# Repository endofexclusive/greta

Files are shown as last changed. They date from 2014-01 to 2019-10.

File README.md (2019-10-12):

# About
Expansion board for the Amiga A500 computer providing SDRAM, Secure Digital
mass storage and Ethernet interface.

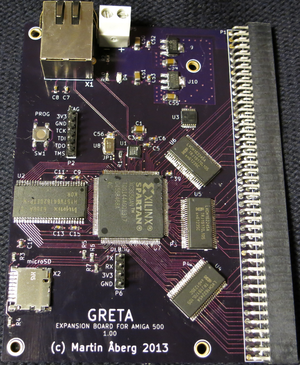
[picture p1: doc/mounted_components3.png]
board


# Features
- Attaches to the Amiga A500 expansion bus
- 8 MiB Fast RAM
  - Zero wait state
  - Always available to the system via Amiga AUTOCONFIG protocol
- SPI controller
  - For interfacing with Secure Digital storage
- 10/100Mbit Ethernet PHY

# Hardware overview
hw-overview
## FPGA
Xilinx Spartan-3AN is used for control logic. This FPGA device
is equipped with an internal bitstream flash.

## Bus transceivers
The Amiga computer uses 5V signalling while the FPGA and the other
expansion board components operate at 3.3V. Signal level conversion
and bus isolation is solved by using 5V-tolerant 3.3V drivers for
signals between the computer to the expansion board.

## Bus protocol
A500 expansion bus protocol is equivalent to the MC68000 processor
bus protocol. The MC68000 bus control signals are sampled by the
FPGA, synchronized, and bridged to an internal custom bus protocol
with time-slots allocated to on-board peripherals.

## Voltage regulators
3.3V and 1.2V are generated by on-board voltage regulators, powered
by the expansion bus connector.

## Clocking
A 50 MHz input clock is generated by the Ethernet PHY. This clock
is synchronous with the PHY RMII signals. The FPGA logic and SDRAM
operate at 133 MHz.

# Status
- Full support for the 8 MiB zero waitstate SDRAM is implemented.

- AmigaOS AUTOCONFIG for device discovery implemented.

- An SPI controller is implemented and is currently being used for
  developing an AmigaOS compliant disk controller driver with SCSI
  emulation.

- An Ethernet MAC with DMA is still to be implemented.

- Gerber files are readily available and can be sent to a PCB
  manufacturer for production. Refer to the schematic files for
  bill of materials (BOM).

# Documentation
Details of the design is documented in the
[Technical description](greta.pdf).

Schematic and layout files are available in the
[pcb](pcb) directory.
A PDF rendering of the schematic can be found in
[doc/schematic.pdf](doc/schematic.pdf).

# Tools
The following tools have been used in the development of hardware
and HDL:
- **KiCad**: schematic and PCB layout
- **GHDL**: RTL simulation and testbenches
- **Xilinx ISE**: Xilinx FPGA synthesis and layout

# Authors
Martin Åberg - <martin@fripost.org>

# License
All schematics, PCB layout and VHDL code described in this document
are released under the GNU General Public License.

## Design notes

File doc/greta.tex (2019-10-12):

\documentclass[a4paper]{report}
\usepackage[english]{babel}
\usepackage{siunitx}
\usepackage[utf8]{inputenc}
\usepackage{listings}
%See listings manual for parameters!!!
\usepackage{listings}
\lstset{
    language=VHDL,
%    basicstyle=\ttfamily
    basicstyle=\footnotesize \ttfamily
    % Fix for character in license unknown to "listings".
    \lstset{literate={Å}{{\AA}}1}
}

\usepackage{booktabs}
\usepackage{tikz-timing}[2009/12/09]
% Use tikz-timing library 'counters' to define a counter character.
% This character draws a 'D{<counter value>}' and increases the counter
% value by one. A reset character which resets the counter value 
% (by default to 1) is also defined.
\usetikztiminglibrary[new={char=Q,reset char=R}]{counters}

\usepackage{hyperref}
\hypersetup{colorlinks, 
           citecolor=black,
           filecolor=black,
           linkcolor=black,
           urlcolor=black,
           bookmarksopen=true,
           pdftex}

\hfuzz = .6pt % avoid black boxes

\title{GRETA\\Technical description}
\author{Martin Åberg \\ }
\pagestyle{headings}
\begin{document}
\maketitle
Copyright (C) 2014 Martin Åberg.\newline

Permission is granted to copy, distribute and/or modify this
document under the terms of the GNU Free Documentation License,
Version 1.3 or any later version published by the Free Software
Foundation; with no Invariant Sections, no Front-Cover Texts,
and no Back-Cover Texts.  A copy of the license is included
in the section entitled "GNU Free Documentation License".
\tableofcontents

\chapter{Introduction}
This document is a technical description of the GRETA expansion
board for Amiga 500. The intended audience is any person who
wants to learn more about how to develop hardware for the Amiga
computer in general, and especially the one who wants to develop
the GRETA expansion further.

All schematics, PCB layout and VHDL code described in this
document are released under the GNU General Public License,
version 3. Gerber files are readily available and can be sent
to a PCB manufacturer for production. Refer to the schematic
files for bill of materials (BOM).

As of January 2014, some features are still to be implemented
in VHDL as well as corresponding software device drivers on
the Amiga.

Feel free to contact the original author at
. Also feel free and
welcome to develop this project further under the current
license and report your progress to the author. Cheerful
support and cooperation will be provided. :-)

\section{Background}
The Amiga 500 computer, based on the Amiga platform, became
popular in the late eighties for combining low-cost, a powerful
CPU (Motorola MC68000), advanced multimedia functionality
and a well-designed operating system. The Amiga platform
was designed to be a basis for business, creative computing,
video production, as well as pure game machines of its times.
Hardware expandability and modularity was designed into the
architecture from start. The auto-configuration protocol,
AUTOCONFIG, is an example of this (more on this later).

A set of on-board custom hardware chips were responsible
for DMA-powered multimedia functionality including graphics,
hardware sprites, memory copying, four channels of digital
audio, and more.

Amiga 500 came as standard with memory configurations of
512KiB or 1024KiB. This memory resides on a memory bus which is
shared between the main CPU and the Amiga custom chips. When
the custom chips are heavily utilized, only a fraction of the
memory bus time is available for the CPU to use.

For more information on the Amiga architecture, see
\cite{a500_techref}.

\section{GRETA Features}
GRETA expansion board is a hardware expansion which connects
to the expansion bus on the Amiga 500 computer and adds the
following features to the system\footnote{As of January 2014,
only Fast RAM with AUTOCONFIG is implemented in HDL. Preparation
for the other peripherals is done in terms of AUTOCONFIG and
DMA access to the SDRAM. All the necessary hardware components
are there aswell.}.

\begin{description}
  \item[8 MiB Fast RAM] \hfill \\
    The RAM is always available to the main CPU. There are no
    wait states involved so throughput is 3.4 MiB/s for a PAL
    Amiga 500. This also holds when the on-board peripherals described
    below are used. It is installed automatically in the system
    at boot by using the AUTOCONFIG protocol.

  \item[micro SD] \hfill \\
    A uSD flash memory controller is used for non-volatile
    storage. All accesses are performed by DMA to the 8 MiB
    Fast RAM.  AUTOCONFIG together with custom device drivers
    loaded from the GRETA board is responsible for allowing
    booting from uSD memory.

  \item[Ethernet controller] \hfill \\
    A custom network controller that allows for 10/100MBit Ethernet networking. The network controller performs DMA to the 8 MiB Fast RAM.

  \item[External I/O] \hfill \\
    An external I/O pin header allows for use for dirverse use. For example a fast UART can be implemented. Another option is to use it as
    a debug port implementing the GDB Remote Serial protocol \cite{gdbserial}.

\end{description}

\section{Expandability of GRETA}
The GRETA expansion board can in principle be the basis of any
peripheral suitable for the expansion bus of Amiga 500. For
example a graphics or SATA adapter could be implemented by
fitting the appropriate controller chip which is directed by
the FPGA chip.

Also, with minor modification, the board can be made to fit
the ZORRO II bus in Amiga 2000/3000/4000. It could in principle
be achieved by modifying the physical connection and rerouting
the AUTOCONFIG signals as appropriate.

\section{Hardware overview}
\begin{figure}
\centering

\caption{Hardware block diagram of the GRETA expansion
board. Blue boxes indicate on-board devices. Pink boxes are
external connectors.}
\label{hw_overview}
\end{figure}

Figure \ref{hw_overview} illustrates the hardware components
constituting the GRETA expansion board.  For more details,
appendix \ref{greta_sch} contains the electronic schematics
the GRETA expansion board. The schematic files are also the
hardware documentation. Everything needed to reproduce the
hardware is included.

The PCB itself is routed on four layers with the following
stack-up from top to bottom: Signal, ground, 3.3V, signal.
Great care has been taken to achieve good signal integrity
properties. For example, no bus signals or fast switching
signals are routed through vias. Routing is tight; only two
pins on the FPGA are unconnected.

All components, except for external connectors, are surface
mounted. 0603 package is chosen for all resistors and most
capacitors.

Figure \ref{mounted_components2} shows the PCB
with components mounted and figure \ref{greta_connected2} the
expansion board connected to the host computer. Figures
\ref{greta_osh_top} and \ref{greta_osh_bottom} are images rendered
from the Gerber files supplied to the PCB manufacturer.

\begin{figure}
\centering
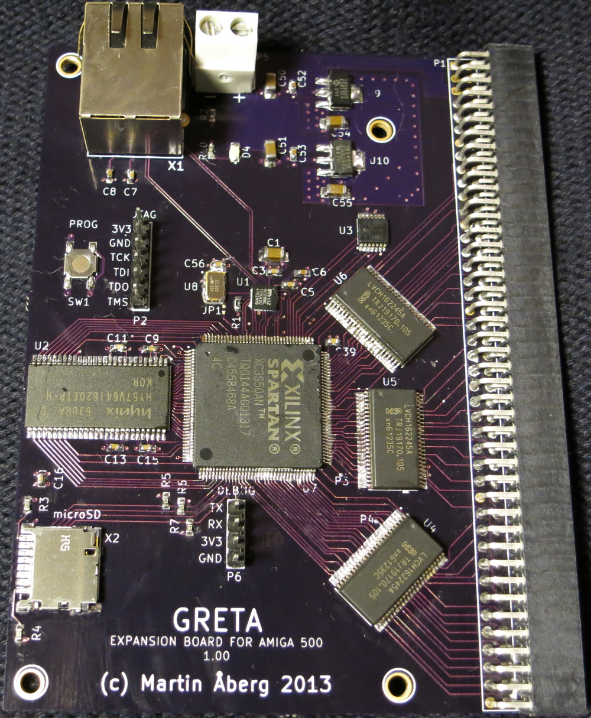
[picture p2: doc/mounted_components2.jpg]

\caption[LoF entry]{Top side of GRETA expansion board. On the
right edge is the connector to the Amiga computer expansion
bus. The expansion connector has all its signals connected to
three 16-bit transceivers and a 6-bit open drain driver.

Down to the left is the microSD card slot and above it the
SDRAM. At top left is the RJ45 Ethernet connector and next to
it the connector for external power.

The large chip in the middle is the Xilinx FPGA. Above it are
clock oscillator and Ethernet PHY.

Between the expansion connector and external power are two
voltage regulators which generate 1.2V and 3.3V.}
\label{mounted_components2}
\end{figure}

\begin{figure}
\centering
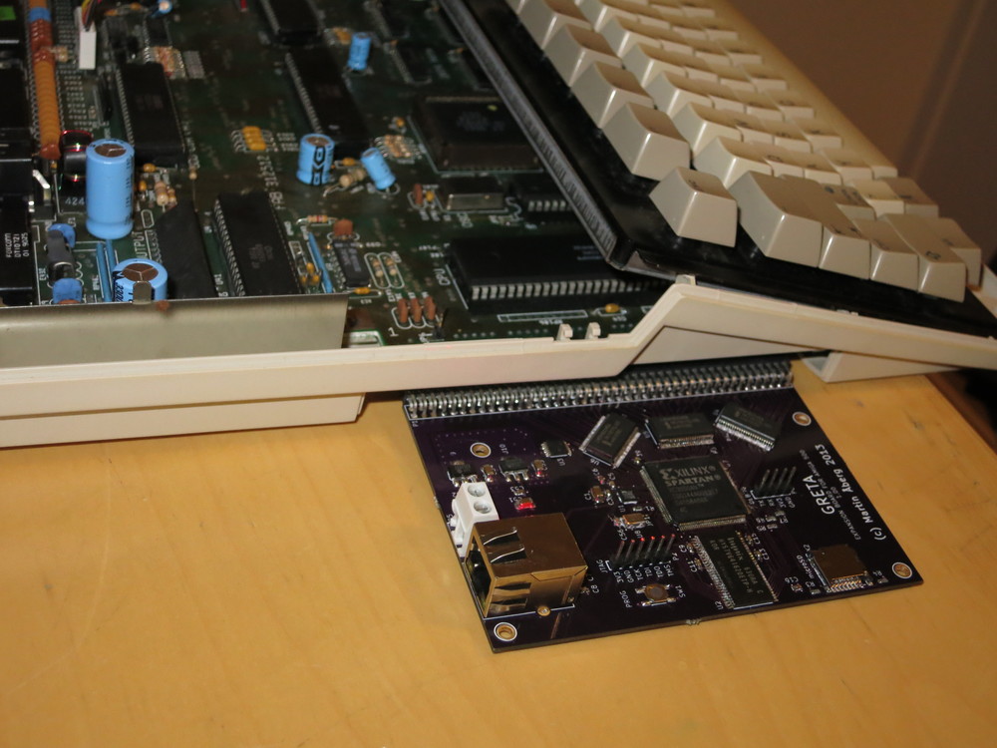
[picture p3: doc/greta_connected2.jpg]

\caption{The expansion board connects on the left side of the
computer. The large chip parallel to the expansion is the Motorola
MC68000 CPU.}
\label{greta_connected2}
\end{figure}

\begin{figure}
\centering
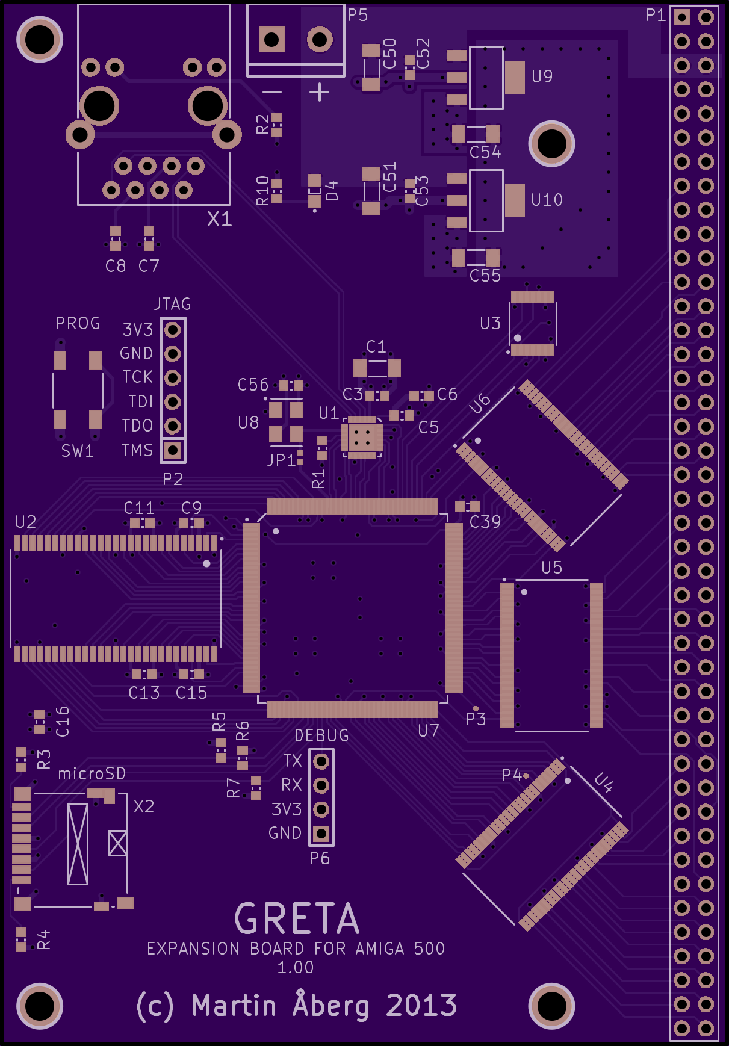
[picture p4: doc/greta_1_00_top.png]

\caption{PCB top.}
\label{greta_osh_top}
\end{figure}

\begin{figure}
\centering
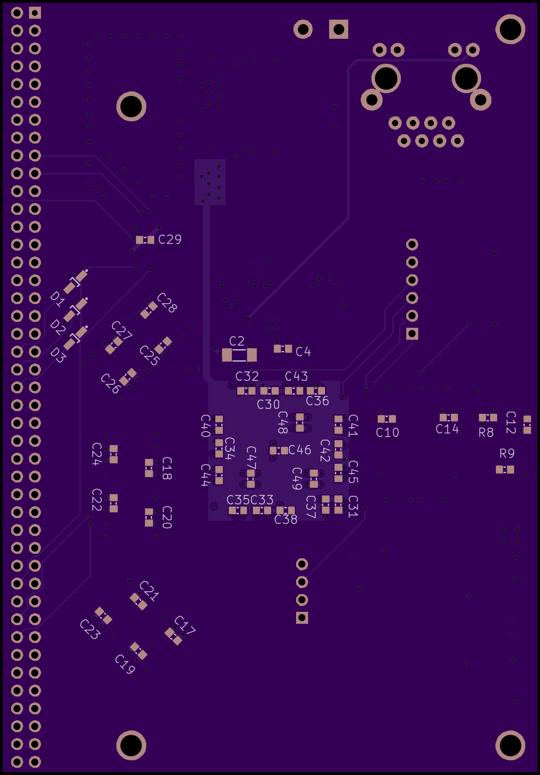
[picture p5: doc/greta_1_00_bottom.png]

\caption{PCB bottom.}
\label{greta_osh_bottom}
\end{figure}
\subsection{Notes on the hardware design}
The Amiga computer uses 5V TTL signals througout while the FPGA
and the other GRETA components are rated at 3.3V and thus some
signal level conversion is needed. The solution is to use 5V
tolerant drivers for bidirectional signals and unidirectional
signals from the computer to the expansion board. A 16-bit
bidirectional transceiver, NXP 74LVCH162245A, a component with
built-in 30 ohm series termination resistors, solves this. For
signals going from the FPGA back to the computer, the device
SN74LVC07A is used. It has TTL level tolerant open-drain outputs
which fits well with the open collector inputs on the Amiga.

RMII is chosen over MII as Media Independen Interface for the
Ethernet PHY. This reduces pin-count. As a bonus, the selected
chip has a PLL that can feed the FPGA with a clock signal.

\section{Tools}
The following software tools have been used in the development
of the GRETA hardware and HDL.
\begin{description}
  \item[Arch Linux] \hfill \\
  Operating system, tools and infrastructure.
  \item[KiCad, build (2013-may-18)-stable] \hfill \\
  Schematic capture and PCB layout.
  \item[GNU Make] \hfill \\
  Dependecy tracking for compiling documentation and HDL code.
  \item[GHDL 0.30dev (20100112)] \hfill \\
  Functional simulation of HDL code.
  \item[Xilinx ISE 14.6] \hfill \\
  Development environment for Xilinx FPGA.
  \item[ASM-One V1.20] \hfill \\
  Macro-assembler and development environment for the Amiga computer.
  \item[Git] \hfill \\
  Revision control.
  \item[LibreOffice Draw] \hfill \\
  Vector graphics.
  \item[VIM] \hfill \\
  Text editing.
  \item[\LaTeX] \hfill \\
  Typesetting text documents.
\end{description}

\section{Errata}
\subsection{Deassert Ethernet PHY reset to get system clock}
The clock input to the FPGA is driven by a PLL in the Ethernet PHY.
For the Ethernet PHY to output the clock to the FPGA, the PHY reset
input must be asserted. The PHY reset input is driven by the FPGA
output designated \texttt{PHY\_nRST}.

\textbf{Workaround}: Always drive a high value on the FPGA output
pin \texttt{PHY\_nRST}.

\subsection{microSD pins are reversed}
The pinout of the microSD socket does not match the PCB footprint.

\textbf{Workaround}: Rotate the microSD connector $180^\circ$ or
correct the footprint.

\chapter{HDL Overview}
This chapter gives an overview of the GRETA HDL architecture.
All VHDL source files are included in appendix \ref{hdl_code}.
During the devolopment of the HDL components, a set of test
benches were developed. These test benches are not included
in the listings in this document. They are however provided
in the GRETA file distribution.

The top-level module is contained in \texttt{greta.vhdl}
with the port definition described in table \ref{top_level}.
The VHDL package in file \texttt{greta\_pkg.vhdl} contains
type definitions, address constants, bit constants and helper
functions for the other HDL modules. Even though several custom
types are used in the design, the top level ports only use
types defined in \texttt{IEEE.STD\_LOGIC\_1164}.

Figure \ref{hdl_overview} illustrates how the HDL
components are related to each other.

\begin{figure}
\centering

\caption{HDL block diagram of GRETA. Each box represents one
HDL component. All components are implemented using VHDL and
are realised in FPGA.}
\label{hdl_overview}
\end{figure}

\begin{table}
\begin{tabular}{*3l}    \toprule
\emph{Port}             & \emph{Direction}  & \emph{Description} \\ \midrule
\texttt{CLK25MHZ}       & in  & If \texttt{JP1} is open then this input is undefined. \\
\midrule
\midrule
                            &     & Amiga 500 expansion bus\\
\midrule
\texttt{RL\_nRST}           & in  & Reset\\
\texttt{RL\_nAS}            & in  & Address Strobe\\
\texttt{RL\_nUDS}           & in  & Data Upper Strobe\\
\texttt{RL\_nLDS}           & in  & Data Lower Strobe\\
\texttt{RL\_RnW}            & in  & Read/Write\\
\texttt{RL\_CDAC}           & in  & Amiga system clock with 90$^{\circ}$ phase offset\\
\texttt{RL\_nOVR}           & out & Override internal generation of \texttt{nDTACK}\\
\texttt{RL\_nINT2}          & out & Amiga interrupt level 2\\
\texttt{RL\_nINT6}          & out & Amiga interrupt level 6\\
\texttt{RL\_nINT7}          & out & Non-maskable interrupt\\
\texttt{RL\_nDTACK}         & out & Data Acknowledge\\
\texttt{RL\_A[23:1]}        & in  & Address bus \\
\texttt{RL\_D[15:0]}        & inout & Bidirectinal data bus \\
\texttt{RL\_D\_nOE}         & out & Output enable for data bus transceiver \\
\texttt{RL\_D\_TO\_GRETA}   & out & Direction of data bus transceiver\\
\midrule
\midrule
                            &       & SDRAM interface \\
\midrule
\texttt{SDRAM\_CLK}         & out   & Clock \\
\texttt{SDRAM\_CKE}         & out   & Clock Enable \\
\texttt{SDRAM\_nRAS}        & out   & Row Address Strobe \\
\texttt{SDRAM\_nCAS}        & out   & Column Address Strobe \\
\texttt{SDRAM\_nWE}         & out   & Write Enable \\
\texttt{SDRAM\_UDQM}        & out   & Upper Data Input/Output Mask \\
\texttt{SDRAM\_LDQM}        & out   & Lower Data Input/Ouput Mask \\
\texttt{SDRAM\_BA[1:0]}     & out   & Bank Address \\
\texttt{SDRAM\_A[11:0]}     & out   & Address \\
\texttt{SDRAM\_DQ[15:0]}    & inout & Data bus \\
\midrule
\midrule
                    &       & microSD interface (SPI) \\
\midrule
\texttt{SPI\_CLK}   & out   & Clock (SCLK) \\
\texttt{SPI\_nCS}   & out   & Chip Select (SS) \\
\texttt{SPI\_DO}    & out   & Data Output (MOSI) \\
\texttt{SPI\_DI}    & in    & Data Input (MISO)\\
\midrule
\midrule
                        &       & Ethernet PHY (RMII) \\
\midrule
\texttt{PHY\_nRST}      & out   & Reset \\
\texttt{PHY\_MDC}       & out   & MDIO Clock \\
\texttt{PHY\_MDIO}      & inout & MDIO Data I/O \\
\texttt{RMII\_REF\_CLK} & in    & RMII Clock (50 MHz) \\
\texttt{RMII\_CRS\_DV}  & in    & RMII Carrier Sense/Data Valid \\
\texttt{RMII\_RXD[1:0]} & in    & RMII Receive Data \\
\texttt{RMII\_TXD[1:0]} & out   & RMII Transmit Data \\
\texttt{RMII\_TX\_EN}   & out   & RMII Transmit Data Enable \\
\midrule
\midrule
                    &       & UART/DEBUG interface \\
\midrule
\texttt{DEBUG\_RX}  & in    & \\
\texttt{DEBUG\_TX}  & out   & \\
\midrule
\bottomrule
 \hline
\end{tabular}
\caption{GRETA top level ports.}
\label{top_level}
\end{table}

A clock synthesizer unit (DCM) in the FPGA is used to generate
the 133 MHz clock which is used in the internal logic. It is
commonly referred to as the \texttt{clk} signal.

\section{AUTOCONFIG}
According to the AUTOCONFIG protocol of the Amiga computer
ZORRO II specification \cite{a500_techref}, a peripheral
device can be in one of the states \texttt{UNCONFIGURED},
\texttt{CONFIGURED} or \texttt{SHUT\_UP}. After reset,
every device is \texttt{UNCONFIGURED} and responds to bus
accesses in the address space \texttt{\$E80000-\$E8FFFF}
if its \texttt{nCONFIG\_IN} signal is asserted. The system
software reads certain registers from the device in this
area and eventually issues a write to relocate the device
to another address space, typically somewhere inside
\texttt{\$E90000-\$EFFFFF} or \texttt{\$200000-\$9FFFFF}
depending on size requirements. The device is now
\texttt{CONFIGURED} and passes its \texttt{nCONFIG\_OUT} signal
to the next device's \texttt{nCONFIG\_IN}. This procedure is
repeated until all devices in the system are configured.

If the system for some reason choses not to configure a device,
the device is forced into the \texttt{SHUT\_UP} state by writing
to a dedicated register. In this state the device just passes
on its \texttt{nCONFIG\_OUT} and must never respond again
until the next reset.

The AUTOCONFIG space is the address area from
\texttt{\$E80000-\$EFFFFF}. Inside this area there are eight
equaly sized slots.

Definitions and helper functions for the AUTOCONFIG protocol
can be found in the VHDL package \texttt{autoconfig\_pkg}.

\chapter{Bus interface}
The bus decoder is responsible for decoding asynchronous
MC68000 bus signals and exporting a synchronous read/write
protocol to the GRETA peripherals.

\section{Specification}
The internal bus protocl is presented in table
\ref{bus_interface}.

A pulse on \texttt{req} means that \texttt{nwe}, \texttt{addr}
and \texttt{wdata} are valid and will remain so for at least
34 \texttt{clk} periods\footnote{To be decided. This is a
safe minimum.}.

Each GRETA peripheral device holds its \texttt{rdata}
output valid as long as the peripheral is addressed, and zero
otherwise. This allows for all GRETA peripherals to have their
rdata outputs OR-wired to the bus interface \texttt{rdata}
input. An addressed GRETA peripheral must respond to a read
request in 34 \texttt{clk} periods\footnote{To be decided. This
is a safe minimum.} by asserting its \texttt{dev\_select}
signal. The individual \texttt{dev\_select} signals
are OR:ed together at the top level. The bus interface
\texttt{dev\_selected} is used to determine if the bus
transceivers shall drive data towards the Amiga.

The Amiga ZORRO II expansion bus protocol also defines the
signal \texttt{XRDY} which can be used to delay individual
bus accesses. \texttt{XRDY} is not used in the GRETA design
and is not even connected to the GRETA hardware.

\begin{table}
\begin{tabular}{*4l}    \toprule
\emph{Port} & \emph{Type}  & \emph{Direction}  & \emph{Description} \\ \midrule
\texttt{clk}        & \texttt{std\_logic}& in  & GRETA clock\\
\texttt{cpu\_reset} & \texttt{std\_logic}& out & Synchronous reset, activated by Amiga. \\
\midrule
\midrule
                    &                   &       & Internal bus interface \\
\midrule
\texttt{req}        & \texttt{std\_logic}& out & Pulsed once for each 68000 read/write \\
\texttt{nwe}        & \texttt{bus\_nwe} & out  & Upper and lower byte select for write.\\
                    &                   &      & "11" means read. \\
\texttt{addr}       & \texttt{bus\_addr}& out  & Word destination for read and write transfers \\ 
\texttt{wdata}      & \texttt{bus\_data}& out  & WRITE data \\
\texttt{rdata}      & \texttt{bus\_data}& in   & READ data \\
\texttt{dev\_select}& \texttt{std\_logic}& in  & An on-board peripheral is selected \\
\midrule
\bottomrule
 \hline
\end{tabular}
\caption{Bus interface, internal interface ports.}
\label{bus_interface}
\end{table}

\section{Implementation}
All input signals from the Amiga expansion bus are synchronized
before use in the GRETA clock domain. Control signals have two
synchronizer stages. Stability of sampled data and address
bus signals are assured by the control signals according to
the MC68000 bus protocol. Furthermore, all inputs and outputs
have their registers in the FPGA IO pads.

\chapter{SDRAM Controller}
The SDRAM controller offers a user interface to a physical
SDRAM chip.  Design goals are to provide determinism and an
easy to use control interface.  Performance demands are set
by client access requirements.

All timings in this chapter referes to a \emph{Hynix} SDRAM
chip clocked at 133 MHz and CAS latency of three.

\section{Time resource estimations for SDRAM clients}
The access time requirements for each SDRAM client presented
in the previous chapter are presented in this section and
summarised in Table \ref{sdram_clients}.

\begin{table}
\begin{tabular}{*4l}    \toprule
\emph{Client} & \emph{Period} & \emph{Execution time} & \emph{Deadline} \\
\midrule
Fast RAM      & 55    & 8 & 34   \\
Disk          & 85    & 8 & 85   \\
MAC TX        & 213   & 8 & 213  \\
MAC RX        & 213   & 8 & 213  \\
Auto refresh  & 2083  & 9 & 2083 \\
\bottomrule
 \hline
\end{tabular}
\caption{Real time requirements for clients issuing DMA
operations on SDRAM.  All time values are in units of 133 MHz
clock periods, 7.5ns.  Read and write execution times are based on single 16
bit word access with CAS latency of 3 cycles. Auto refresh is 9 cycles
for this configuration.}
\label{sdram_clients}
\end{table}

\subsection{Fast RAM Controller}
For the ZORRO II bus interface on an NTSC Amiga 500,
accesses can be performed at most once every fourth 7.16MHz
clock cycle \cite{mc68000um}.  The bus read period and
deadlines are derived from \cite{mc68000um} and actual signal
measurements.

Deadline for a bus read is limited by the time at which Motorola
68000 bus samples read data (falling edge leading to bus cycle
state S7).  For bus write, the deadline is effectively the time
at which a following of bus read may occur.  Requests from
bus read and bus write can never be active at the same time
so they are combined to one task in Table \ref{sdram_clients}
to simplify calculations. As a consequence of this, timing
budget for the bus interface is a bit pessimistic.

\subsection{Disk Controller}
A bitrate of 25Mbit/s for Secure Digital over SPI gives a
maximum throughput of 2.98MiB/s. The number of 7.5ns periods
per 16bit SDRAM access is
$85 \le \frac{16 bit}{25 Mbit/s}\cdot \frac{1}{7.5 ns}$.

\subsection{Ethernet MAC}
Periods and deadlines for MAC RX and MAC TX are based on
\si{10}{Mbit} Ethernet in full-duplex mode. With the presented
timing guarantees, only a very narrow FIFO buffer is required
to transfer data between the Ethernet PHY clock domain and
SDRAM. 

The SDRAM access period time for a sustained transfer in each
direction, expressed as 7.5ns periods, is
$213 \le \frac{16 bit}{10 Mbit/s}\cdot \frac{1}{7.5 ns}$.

If support for two word bursts is added to the SDRAM
controller, then \si{100}{Mbit} full-duplex can be supported
without affecting the real time properties of the other RAM
clients. (Though this is possible in theory, the Amiga 500 running
a TCP/IP stack with SANA-II driver interface would never handle
rates above \si{10}{Mbit} anyway.)

\subsection{Auto refresh}
The SDRAM requires 64 refresh operation every 4096 ms. In terms
of 7.5ns periods, this is
$2083 \le \frac{64 ms}{4096}\cdot \frac{1}{7.5 ns}$.

\section{SDRAM Scheduling}
To solve the SDRAM scheduling problem, a static off-line
approach is used. A time table is pre-calculated, in which
each client has its dedicated time slot. An offset pointer
iterates over the calendar slots. When the pointer has reached
the end of the table it restarts from the top again.

This satisfies the goal of determinism and simplicity. Of
course, it must be assured that each client will meet its deadline.

To simplify matters, the accessed bank is always precharged
after an access. Furthermore, if a client does not issue a
request in its designated time slot, the SDRAM will carry out
an unused read operation anyway.  Note that self refreshes
are scheduled just as an ordinary client.

Also note that scheduling of requests to the SDRAM
resource as presented in this section, will result in accesses
not being served in the same time order as they were requested.
Because of this, any of the peripherals must send its interrupt
back to the computer only after an access has been acknowledged
by the RAM arbiter.  Anyhow, requests made by the same client
will always be served in the same order as they were issued.

Table \ref{calendar} illustrates the client calendar. The
tightest timing budget is for a \emph{Disk} request
arriving at time 10 and finishes at time 89, resulting in a
response time of 79 time units.

\begin{table}
\begin{tabular}{*3l}    \toprule
\emph{Offset} & \emph{Time}   & \emph{Client} \\
\midrule
0         &  0 -  8     & Fast RAM      \\
1         &  9 - 17     & Disk          \\
2         & 18 - 26     & Fast RAM      \\
3         & 27 - 35     & MAC TX        \\
4         & 36 - 44     & Fast RAM      \\
5         & 45 - 53     & MAC RX        \\
6         & 54 - 62     & Fast RAM      \\
7         & 63 - 71     & Auto refresh  \\
\midrule            
0         & 72 - 80     & Fast RAM      \\
1         & 81 - 89     & Disk          \\
$\vdots$  & $\vdots$    & $\vdots$      \\
\bottomrule
 \hline
\end{tabular}
\caption{Calendar for static scheduling of the SDRAM resource.
The unit of time offset is one period of a 133 MHz clock (7.5ns).
Calendar has eight positions and repeats after offset 7.}
\label{calendar}
\end{table}

\section{Specification}
Each client communicates with the SDRAM controller
using an in/out signal pair with types \texttt{ram\_bus}
and \texttt{std\_logic} respectively. An example is the
\texttt{fast}/\texttt{fast\_ack} pair. All clients share the
read data bus \texttt{rdata}. See table \ref{ram_bus_type}
for a description of the \texttt{ram\_bus} record type.

Transfers are 16 bit wide but for write accesses, it is
possible to select target bytes individually with the mask
signal \texttt{nwe}.

\begin{table}
\begin{tabular}{*3l}    \toprule
\emph{Member}   & \texttt{Type}         & \emph{Description} \\ \midrule
\texttt{req}    & \texttt{std\_logic}   & Assert high to issue an SDRAM request. \\
\texttt{nwe}    & \texttt{bus\_nwe}     & Upper and lower byte select for write.\\
                &                       & \texttt{"11"} means read. \\
\texttt{addr}   & \texttt{bus\_addr}    & Target address for request. \\
\texttt{wdata}  & \texttt{bus\_data}    & Write data. \\
\bottomrule
 \hline
\end{tabular}
\caption{Record type definition for \texttt{ram\_bus.} The type
is used by SDRAM clients.}
\label{ram_bus_type}
\end{table}

To do an SDRAM request, the client sets its \texttt{req} signal
high and holds it high until the corresponding \texttt{ack}
signal goes high (pulse). The record members \texttt{nwe},
\texttt{addr} and \texttt{wdata} must be constant for the
duration of asserted \texttt{req}.  If it was a read request,
then \texttt{rdata} is valid only in the same clock cycle as
\texttt{ack} is pulsed.

Table \ref{sdram_interface} illustrates the internal HDL
interface to the SDRAM controller.

\begin{table}
\begin{tabular}{*4l}    \toprule
\emph{Port}         & \texttt{Type}         & \emph{Direction}  & \emph{Description} \\ \midrule
\texttt{clk}        & \texttt{std\_logic}   & in  & GRETA clock \\
\texttt{reset}      & \texttt{std\_logic}   & in  & Synchronous reset \\
\midrule
\texttt{ready}      & \texttt{std\_logic}   & out & Controller is ready for requests \\
\midrule
\midrule
                    &                   &       & Fast RAM client \\
\midrule
\texttt{fast}       & \texttt{ram\_bus}     & in  & Control structure for accesses by Disk \\
\texttt{fast\_ack}  & \texttt{std\_logic}   & out & Acknowledge signal for Disk  \\
\midrule
\midrule
                    &                   &       & microSD client \\
\midrule
\texttt{disk}       & \texttt{ram\_bus}     & in  & Control structure for accesses by Disk \\
\texttt{disk\_ack}  & \texttt{std\_logic}   & out & Acknowledge signal for Disk  \\
\midrule
\midrule
                    &                   &       & Ethernet MAC client \\
\midrule
\texttt{mactx}      & \texttt{ram\_bus}     & in  & Control structure for accesses by MAC TX \\
\texttt{mactx\_ack} & \texttt{std\_logic}   & out & Acknowledge signal for MAC TX \\
\midrule
\texttt{macrx}      & \texttt{ram\_bus}     & in  & Control structure for accesses by MAC RX \\
\texttt{macrx\_ack} & \texttt{std\_logic}   & out & Acknowledge signal for MAC RX \\
\midrule
\midrule
                    &                   &       & Common read data bus \\
\midrule
\texttt{rdata}      & \texttt{bus\_data}    & out & Read data, only valid at the corresponding \texttt{\_ack=1} \\ 
\midrule
\bottomrule
 \hline
\end{tabular}
\caption{SDRAM component, interface for internal ports.}
\label{sdram_interface}
\end{table}

\chapter{Fast RAM Controller}
The Fast RAM controller is responsible for implementing the AUTOCONFIG protol
for configuring RAM at system start and then responds to Fast RAM accesses
in the Amiga address range \texttt{\$200000-\$9FFFFF}.

This Amiga address range needs 23 bits to describe 16-bit word
locations. This is a \si{16}{MiB} range but only \si{8}{MiB}
in this range is used for accessing actual RAM. An important
observation is that bit 23 is not significant for addressing
to the SDRAM.

In fact, bit 23 can be ignored. This can be seen by splitting the
Fast RAM address range into three parts and observe the mappings on SDRAM (table \ref{fast_ranges}.

\begin{table}
\begin{tabular}{*3l}    \toprule
\emph{Amiga address}   & \texttt{SDRAM address}         & \texttt{Size} \\ \midrule
\texttt{\$200000-\$3FFFFF} (bit 23=0)& \texttt{\$200000-\$9FFFFF} & \si{2}{MiB}\\
\texttt{\$400000-\$7FFFFF} (bit 23=0)& \texttt{\$400000-\$7FFFFF} & \si{4}{MiB}\\
\texttt{\$800000-\$9FFFFF} (bit 23=1)& \texttt{\$000000-\$1FFFFF} & \si{2}{MiB}\\
\bottomrule
 \hline
\end{tabular}
\caption{Mapping of the external RAM in the Amiga address space to
SDRAM address space.}
\label{fast_ranges}
\end{table}

\section{Specification}
The HDL port interface of the Fast RAM component consists of
the bus interface and the SDRAM interface as described above.

\chapter{Disk Controller}
\section{Specification}
\subsection{User registers}
\section{Implementation}

\appendix
\chapter{Electronic schematics}
\label{greta_sch} 
\begin{centering}













\end{centering}

\chapter{HDL code}
\label{hdl_code}

\section{GRETA types, constants and functions}
    \lstinputlisting{../hdl/greta_pkg.vhdl}

\newpage
\section{GRETA}
    \lstinputlisting{../hdl/greta.vhdl}

\newpage
\section{Bus Interface}
    \lstinputlisting{../hdl/bus_interface/bus_interface.vhdl}

\newpage
\section{SDRAM Controller}
    \lstinputlisting{../hdl/sdram/sdram.vhdl}

\newpage
\section{Fast RAM Controller}
    \lstinputlisting{../hdl/fast/fast.vhdl}

\newpage
\section{Disk Controller}
    \lstinputlisting{../hdl/disk/disk.vhdl}

\chapter{GNU Free Documentation License}
\phantomsection  % so hyperref creates bookmarks
\addcontentsline{toc}{chapter}{GNU Free Documentation License}
%\label{label_fdl}

 \begin{center}

       Version 1.3, 3 November 2008

 Copyright \copyright{} 2000, 2001, 2002, 2007, 2008  Free Software Foundation, Inc.
 
 \bigskip
 
     \texttt{<http://fsf.org/>}
  
 \bigskip
 
 Everyone is permitted to copy and distribute verbatim copies
 of this license document, but changing it is not allowed.
\end{center}

\begin{center}
{\bf\large Preamble}
\end{center}

The purpose of this License is to make a manual, textbook, or other
functional and useful document ``free'' in the sense of freedom: to
assure everyone the effective freedom to copy and redistribute it,
with or without modifying it, either commercially or noncommercially.
Secondarily, this License preserves for the author and publisher a way
to get credit for their work, while not being considered responsible
for modifications made by others.

This License is a kind of ``copyleft'', which means that derivative
works of the document must themselves be free in the same sense.  It
complements the GNU General Public License, which is a copyleft
license designed for free software.

We have designed this License in order to use it for manuals for free
software, because free software needs free documentation: a free
program should come with manuals providing the same freedoms that the
software does.  But this License is not limited to software manuals;
it can be used for any textual work, regardless of subject matter or
whether it is published as a printed book.  We recommend this License
principally for works whose purpose is instruction or reference.

\begin{center}
{\Large\bf 1. APPLICABILITY AND DEFINITIONS\par}
\phantomsection
\addcontentsline{toc}{section}{1. APPLICABILITY AND DEFINITIONS}
\end{center}

This License applies to any manual or other work, in any medium, that
contains a notice placed by the copyright holder saying it can be
distributed under the terms of this License.  Such a notice grants a
world-wide, royalty-free license, unlimited in duration, to use that
work under the conditions stated herein.  The ``\textbf{Document}'', below,
refers to any such manual or work.  Any member of the public is a
licensee, and is addressed as ``\textbf{you}''.  You accept the license if you
copy, modify or distribute the work in a way requiring permission
under copyright law.

A ``\textbf{Modified Version}'' of the Document means any work containing the
Document or a portion of it, either copied verbatim, or with
modifications and/or translated into another language.

A ``\textbf{Secondary Section}'' is a named appendix or a front-matter section of
the Document that deals exclusively with the relationship of the
publishers or authors of the Document to the Document's overall subject
(or to related matters) and contains nothing that could fall directly
within that overall subject.  (Thus, if the Document is in part a
textbook of mathematics, a Secondary Section may not explain any
mathematics.)  The relationship could be a matter of historical
connection with the subject or with related matters, or of legal,
commercial, philosophical, ethical or political position regarding
them.

The ``\textbf{Invariant Sections}'' are certain Secondary Sections whose titles
are designated, as being those of Invariant Sections, in the notice
that says that the Document is released under this License.  If a
section does not fit the above definition of Secondary then it is not
allowed to be designated as Invariant.  The Document may contain zero
Invariant Sections.  If the Document does not identify any Invariant
Sections then there are none.

The ``\textbf{Cover Texts}'' are certain short passages of text that are listed,
as Front-Cover Texts or Back-Cover Texts, in the notice that says that
the Document is released under this License.  A Front-Cover Text may
be at most 5 words, and a Back-Cover Text may be at most 25 words.

A ``\textbf{Transparent}'' copy of the Document means a machine-readable copy,
represented in a format whose specification is available to the
general public, that is suitable for revising the document
straightforwardly with generic text editors or (for images composed of
pixels) generic paint programs or (for drawings) some widely available
drawing editor, and that is suitable for input to text formatters or
for automatic translation to a variety of formats suitable for input
to text formatters.  A copy made in an otherwise Transparent file
format whose markup, or absence of markup, has been arranged to thwart
or discourage subsequent modification by readers is not Transparent.
An image format is not Transparent if used for any substantial amount
of text.  A copy that is not ``Transparent'' is called ``\textbf{Opaque}''.

Examples of suitable formats for Transparent copies include plain
ASCII without markup, Texinfo input format, LaTeX input format, SGML
or XML using a publicly available DTD, and standard-conforming simple
HTML, PostScript or PDF designed for human modification.  Examples of
transparent image formats include PNG, XCF and JPG.  Opaque formats
include proprietary formats that can be read and edited only by
proprietary word processors, SGML or XML for which the DTD and/or
processing tools are not generally available, and the
machine-generated HTML, PostScript or PDF produced by some word
processors for output purposes only.

The ``\textbf{Title Page}'' means, for a printed book, the title page itself,
plus such following pages as are needed to hold, legibly, the material
this License requires to appear in the title page.  For works in
formats which do not have any title page as such, ``Title Page'' means
the text near the most prominent appearance of the work's title,
preceding the beginning of the body of the text.

The ``\textbf{publisher}'' means any person or entity that distributes
copies of the Document to the public.

A section ``\textbf{Entitled XYZ}'' means a named subunit of the Document whose
title either is precisely XYZ or contains XYZ in parentheses following
text that translates XYZ in another language.  (Here XYZ stands for a
specific section name mentioned below, such as ``\textbf{Acknowledgements}'',
``\textbf{Dedications}'', ``\textbf{Endorsements}'', or ``\textbf{History}''.)  
To ``\textbf{Preserve the Title}''
of such a section when you modify the Document means that it remains a
section ``Entitled XYZ'' according to this definition.

The Document may include Warranty Disclaimers next to the notice which
states that this License applies to the Document.  These Warranty
Disclaimers are considered to be included by reference in this
License, but only as regards disclaiming warranties: any other
implication that these Warranty Disclaimers may have is void and has
no effect on the meaning of this License.

\begin{center}
{\Large\bf 2. VERBATIM COPYING\par}
\phantomsection
\addcontentsline{toc}{section}{2. VERBATIM COPYING}
\end{center}

You may copy and distribute the Document in any medium, either
commercially or noncommercially, provided that this License, the
copyright notices, and the license notice saying this License applies
to the Document are reproduced in all copies, and that you add no other
conditions whatsoever to those of this License.  You may not use
technical measures to obstruct or control the reading or further
copying of the copies you make or distribute.  However, you may accept
compensation in exchange for copies.  If you distribute a large enough
number of copies you must also follow the conditions in section~3.

You may also lend copies, under the same conditions stated above, and
you may publicly display copies.

\begin{center}
{\Large\bf 3. COPYING IN QUANTITY\par}
\phantomsection
\addcontentsline{toc}{section}{3. COPYING IN QUANTITY}
\end{center}

If you publish printed copies (or copies in media that commonly have
printed covers) of the Document, numbering more than 100, and the
Document's license notice requires Cover Texts, you must enclose the
copies in covers that carry, clearly and legibly, all these Cover
Texts: Front-Cover Texts on the front cover, and Back-Cover Texts on
the back cover.  Both covers must also clearly and legibly identify
you as the publisher of these copies.  The front cover must present
the full title with all words of the title equally prominent and
visible.  You may add other material on the covers in addition.
Copying with changes limited to the covers, as long as they preserve
the title of the Document and satisfy these conditions, can be treated
as verbatim copying in other respects.

If the required texts for either cover are too voluminous to fit
legibly, you should put the first ones listed (as many as fit
reasonably) on the actual cover, and continue the rest onto adjacent
pages.

If you publish or distribute Opaque copies of the Document numbering
more than 100, you must either include a machine-readable Transparent
copy along with each Opaque copy, or state in or with each Opaque copy
a computer-network location from which the general network-using
public has access to download using public-standard network protocols
a complete Transparent copy of the Document, free of added material.
If you use the latter option, you must take reasonably prudent steps,
when you begin distribution of Opaque copies in quantity, to ensure
that this Transparent copy will remain thus accessible at the stated
location until at least one year after the last time you distribute an
Opaque copy (directly or through your agents or retailers) of that
edition to the public.

It is requested, but not required, that you contact the authors of the
Document well before redistributing any large number of copies, to give
them a chance to provide you with an updated version of the Document.

\begin{center}
{\Large\bf 4. MODIFICATIONS\par}
\phantomsection
\addcontentsline{toc}{section}{4. MODIFICATIONS}
\end{center}

You may copy and distribute a Modified Version of the Document under
the conditions of sections 2 and 3 above, provided that you release
the Modified Version under precisely this License, with the Modified
Version filling the role of the Document, thus licensing distribution
and modification of the Modified Version to whoever possesses a copy
of it.  In addition, you must do these things in the Modified Version:

\begin{itemize}
\item[A.] 
   Use in the Title Page (and on the covers, if any) a title distinct
   from that of the Document, and from those of previous versions
   (which should, if there were any, be listed in the History section
   of the Document).  You may use the same title as a previous version
   if the original publisher of that version gives permission.
   
\item[B.]
   List on the Title Page, as authors, one or more persons or entities
   responsible for authorship of the modifications in the Modified
   Version, together with at least five of the principal authors of the
   Document (all of its principal authors, if it has fewer than five),
   unless they release you from this requirement.
   
\item[C.]
   State on the Title page the name of the publisher of the
   Modified Version, as the publisher.
   
\item[D.]
   Preserve all the copyright notices of the Document.
   
\item[E.]
   Add an appropriate copyright notice for your modifications
   adjacent to the other copyright notices.
   
\item[F.]
   Include, immediately after the copyright notices, a license notice
   giving the public permission to use the Modified Version under the
   terms of this License, in the form shown in the Addendum below.
   
\item[G.]
   Preserve in that license notice the full lists of Invariant Sections
   and required Cover Texts given in the Document's license notice.
   
\item[H.]
   Include an unaltered copy of this License.
   
\item[I.]
   Preserve the section Entitled ``History'', Preserve its Title, and add
   to it an item stating at least the title, year, new authors, and
   publisher of the Modified Version as given on the Title Page.  If
   there is no section Entitled ``History'' in the Document, create one
   stating the title, year, authors, and publisher of the Document as
   given on its Title Page, then add an item describing the Modified
   Version as stated in the previous sentence.
   
\item[J.]
   Preserve the network location, if any, given in the Document for
   public access to a Transparent copy of the Document, and likewise
   the network locations given in the Document for previous versions
   it was based on.  These may be placed in the ``History'' section.
   You may omit a network location for a work that was published at
   least four years before the Document itself, or if the original
   publisher of the version it refers to gives permission.
   
\item[K.]
   For any section Entitled ``Acknowledgements'' or ``Dedications'',
   Preserve the Title of the section, and preserve in the section all
   the substance and tone of each of the contributor acknowledgements
   and/or dedications given therein.
   
\item[L.]
   Preserve all the Invariant Sections of the Document,
   unaltered in their text and in their titles.  Section numbers
   or the equivalent are not considered part of the section titles.
   
\item[M.]
   Delete any section Entitled ``Endorsements''.  Such a section
   may not be included in the Modified Version.
   
\item[N.]
   Do not retitle any existing section to be Entitled ``Endorsements''
   or to conflict in title with any Invariant Section.
   
\item[O.]
   Preserve any Warranty Disclaimers.
\end{itemize}

If the Modified Version includes new front-matter sections or
appendices that qualify as Secondary Sections and contain no material
copied from the Document, you may at your option designate some or all
of these sections as invariant.  To do this, add their titles to the
list of Invariant Sections in the Modified Version's license notice.
These titles must be distinct from any other section titles.

You may add a section Entitled ``Endorsements'', provided it contains
nothing but endorsements of your Modified Version by various
parties---for example, statements of peer review or that the text has
been approved by an organization as the authoritative definition of a
standard.

You may add a passage of up to five words as a Front-Cover Text, and a
passage of up to 25 words as a Back-Cover Text, to the end of the list
of Cover Texts in the Modified Version.  Only one passage of
Front-Cover Text and one of Back-Cover Text may be added by (or
through arrangements made by) any one entity.  If the Document already
includes a cover text for the same cover, previously added by you or
by arrangement made by the same entity you are acting on behalf of,
you may not add another; but you may replace the old one, on explicit
permission from the previous publisher that added the old one.

The author(s) and publisher(s) of the Document do not by this License
give permission to use their names for publicity for or to assert or
imply endorsement of any Modified Version.

\begin{center}
{\Large\bf 5. COMBINING DOCUMENTS\par}
\phantomsection
\addcontentsline{toc}{section}{5. COMBINING DOCUMENTS}
\end{center}

You may combine the Document with other documents released under this
License, under the terms defined in section~4 above for modified
versions, provided that you include in the combination all of the
Invariant Sections of all of the original documents, unmodified, and
list them all as Invariant Sections of your combined work in its
license notice, and that you preserve all their Warranty Disclaimers.

The combined work need only contain one copy of this License, and
multiple identical Invariant Sections may be replaced with a single
copy.  If there are multiple Invariant Sections with the same name but
different contents, make the title of each such section unique by
adding at the end of it, in parentheses, the name of the original
author or publisher of that section if known, or else a unique number.
Make the same adjustment to the section titles in the list of
Invariant Sections in the license notice of the combined work.

In the combination, you must combine any sections Entitled ``History''
in the various original documents, forming one section Entitled
``History''; likewise combine any sections Entitled ``Acknowledgements'',
and any sections Entitled ``Dedications''.  You must delete all sections
Entitled ``Endorsements''.

\begin{center}
{\Large\bf 6. COLLECTIONS OF DOCUMENTS\par}
\phantomsection
\addcontentsline{toc}{section}{6. COLLECTIONS OF DOCUMENTS}
\end{center}

You may make a collection consisting of the Document and other documents
released under this License, and replace the individual copies of this
License in the various documents with a single copy that is included in
the collection, provided that you follow the rules of this License for
verbatim copying of each of the documents in all other respects.

You may extract a single document from such a collection, and distribute
it individually under this License, provided you insert a copy of this
License into the extracted document, and follow this License in all
other respects regarding verbatim copying of that document.

\begin{center}
{\Large\bf 7. AGGREGATION WITH INDEPENDENT WORKS\par}
\phantomsection
\addcontentsline{toc}{section}{7. AGGREGATION WITH INDEPENDENT WORKS}
\end{center}

A compilation of the Document or its derivatives with other separate
and independent documents or works, in or on a volume of a storage or
distribution medium, is called an ``aggregate'' if the copyright
resulting from the compilation is not used to limit the legal rights
of the compilation's users beyond what the individual works permit.
When the Document is included in an aggregate, this License does not
apply to the other works in the aggregate which are not themselves
derivative works of the Document.

If the Cover Text requirement of section~3 is applicable to these
copies of the Document, then if the Document is less than one half of
the entire aggregate, the Document's Cover Texts may be placed on
covers that bracket the Document within the aggregate, or the
electronic equivalent of covers if the Document is in electronic form.
Otherwise they must appear on printed covers that bracket the whole
aggregate.

\begin{center}
{\Large\bf 8. TRANSLATION\par}
\phantomsection
\addcontentsline{toc}{section}{8. TRANSLATION}
\end{center}

Translation is considered a kind of modification, so you may
distribute translations of the Document under the terms of section~4.
Replacing Invariant Sections with translations requires special
permission from their copyright holders, but you may include
translations of some or all Invariant Sections in addition to the
original versions of these Invariant Sections.  You may include a
translation of this License, and all the license notices in the
Document, and any Warranty Disclaimers, provided that you also include
the original English version of this License and the original versions
of those notices and disclaimers.  In case of a disagreement between
the translation and the original version of this License or a notice
or disclaimer, the original version will prevail.

If a section in the Document is Entitled ``Acknowledgements'',
``Dedications'', or ``History'', the requirement (section~4) to Preserve
its Title (section~1) will typically require changing the actual
title.

\begin{center}
{\Large\bf 9. TERMINATION\par}
\phantomsection
\addcontentsline{toc}{section}{9. TERMINATION}
\end{center}

You may not copy, modify, sublicense, or distribute the Document
except as expressly provided under this License.  Any attempt
otherwise to copy, modify, sublicense, or distribute it is void, and
will automatically terminate your rights under this License.

However, if you cease all violation of this License, then your license
from a particular copyright holder is reinstated (a) provisionally,
unless and until the copyright holder explicitly and finally
terminates your license, and (b) permanently, if the copyright holder
fails to notify you of the violation by some reasonable means prior to
60 days after the cessation.

Moreover, your license from a particular copyright holder is
reinstated permanently if the copyright holder notifies you of the
violation by some reasonable means, this is the first time you have
received notice of violation of this License (for any work) from that
copyright holder, and you cure the violation prior to 30 days after
your receipt of the notice.

Termination of your rights under this section does not terminate the
licenses of parties who have received copies or rights from you under
this License.  If your rights have been terminated and not permanently
reinstated, receipt of a copy of some or all of the same material does
not give you any rights to use it.

\begin{center}
{\Large\bf 10. FUTURE REVISIONS OF THIS LICENSE\par}
\phantomsection
\addcontentsline{toc}{section}{10. FUTURE REVISIONS OF THIS LICENSE}
\end{center}

The Free Software Foundation may publish new, revised versions
of the GNU Free Documentation License from time to time.  Such new
versions will be similar in spirit to the present version, but may
differ in detail to address new problems or concerns.  See
\texttt{http://www.gnu.org/copyleft/}.

Each version of the License is given a distinguishing version number.
If the Document specifies that a particular numbered version of this
License ``or any later version'' applies to it, you have the option of
following the terms and conditions either of that specified version or
of any later version that has been published (not as a draft) by the
Free Software Foundation.  If the Document does not specify a version
number of this License, you may choose any version ever published (not
as a draft) by the Free Software Foundation.  If the Document
specifies that a proxy can decide which future versions of this
License can be used, that proxy's public statement of acceptance of a
version permanently authorizes you to choose that version for the
Document.

\begin{center}
{\Large\bf 11. RELICENSING\par}
\phantomsection
\addcontentsline{toc}{section}{11. RELICENSING}
\end{center}

``Massive Multiauthor Collaboration Site'' (or ``MMC Site'') means any
World Wide Web server that publishes copyrightable works and also
provides prominent facilities for anybody to edit those works.  A
public wiki that anybody can edit is an example of such a server.  A
``Massive Multiauthor Collaboration'' (or ``MMC'') contained in the
site means any set of copyrightable works thus published on the MMC
site.

``CC-BY-SA'' means the Creative Commons Attribution-Share Alike 3.0
license published by Creative Commons Corporation, a not-for-profit
corporation with a principal place of business in San Francisco,
California, as well as future copyleft versions of that license
published by that same organization.

``Incorporate'' means to publish or republish a Document, in whole or
in part, as part of another Document.

An MMC is ``eligible for relicensing'' if it is licensed under this
License, and if all works that were first published under this License
somewhere other than this MMC, and subsequently incorporated in whole
or in part into the MMC, (1) had no cover texts or invariant sections,
and (2) were thus incorporated prior to November 1, 2008.

The operator of an MMC Site may republish an MMC contained in the site
under CC-BY-SA on the same site at any time before August 1, 2009,
provided the MMC is eligible for relicensing.

\begin{center}
{\Large\bf ADDENDUM: How to use this License for your documents\par}
\phantomsection
\addcontentsline{toc}{section}{ADDENDUM: How to use this License for your documents}
\end{center}

To use this License in a document you have written, include a copy of
the License in the document and put the following copyright and
license notices just after the title page:

\bigskip
\begin{quote}
    Copyright \copyright{}  YEAR  YOUR NAME.
    Permission is granted to copy, distribute and/or modify this document
    under the terms of the GNU Free Documentation License, Version 1.3
    or any later version published by the Free Software Foundation;
    with no Invariant Sections, no Front-Cover Texts, and no Back-Cover Texts.
    A copy of the license is included in the section entitled ``GNU
    Free Documentation License''.
\end{quote}
\bigskip
    
If you have Invariant Sections, Front-Cover Texts and Back-Cover Texts,
replace the ``with \dots\ Texts.''\ line with this:

\bigskip
\begin{quote}
    with the Invariant Sections being LIST THEIR TITLES, with the
    Front-Cover Texts being LIST, and with the Back-Cover Texts being LIST.
\end{quote}
\bigskip
    
If you have Invariant Sections without Cover Texts, or some other
combination of the three, merge those two alternatives to suit the
situation.

If your document contains nontrivial examples of program code, we
recommend releasing these examples in parallel under your choice of
free software license, such as the GNU General Public License,
to permit their use in free software.

\begin{thebibliography}{9}

\bibitem{a500_techref}
  Commodore Business Machines,
  \emph{Commodore A500/A2000 Techincal Reference Manual}.
  1986, 1987.

\bibitem{gdbserial}
  Richard Stallman, Roland Pesch, Stan Shebbs, et al, 
  \emph{Debugging with GDB: The GNU Source-Level Debugger}.
  Free Software Foundation,
  10th Edition,
  2014.
  \url{http://www.gnu.org/software/gdb/documentation/}

\bibitem{mc68000um}
  Motorola, Inc,
  \emph{M68000 User's Manual}.
  Prentice-Hall, Inc,
  8th Edition,
  1990.

\end{thebibliography}

\end{document}

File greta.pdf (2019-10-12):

# GRETA Technical description

Martin ˚Aberg

October 12, 2019

1

Copyright (C) 2014 Martin ˚Aberg.

Permission is granted to copy, distribute and/or modify this document under the terms of the GNU Free Documentation License, Version 1.3 or any later version published by the Free Software Foundation; with no Invariant Sections, no Front-Cover Texts, and no Back-Cover Texts. A copy of the license is included in the section entitled ”GNU Free Documentation License”.

# Contents

1 Introduction | 3
2 HDL Overview | 11
3 Bus interface | 15
4 SDRAM Controller | 17
5 Fast RAM Controller | 21
6 Disk Controller | 22
A Electronic schematics | 23

2

CONTENTS | 3
B HDL code | 27
C GNU Free Documentation License | 50
GNU Free Documentation License | 50

# Chapter 1

# Introduction

This document is a technical description of the GRETA expansion board for Amiga 500. The intended audience is any person who wants to learn more about how to develop hardware for the Amiga computer in general, and especially the one who wants to develop the GRETA expansion further.
All schematics, PCB layout and VHDL code described in this document are released under the GNU General Public License, version 3. Gerber files are readily available and can be sent to a PCB manufacturer for production. Refer to the schematic files for bill of materials (BOM).
As of January 2014, some features are still to be implemented in VHDL as well as corresponding software device drivers on the Amiga.
Feel free to contact the original author at | . Also
feel free and welcome to develop this project further under the current license and report your progress to the author. Cheerful support and cooperation will be provided. :-)

## 1.1 Background

The Amiga 500 computer, based on the Amiga platform, became popular in the late eighties for combining low-cost, a powerful CPU (Motorola MC68000), advanced multimedia functionality and a well-designed operating system. The Amiga platform was designed to be a basis for business, creative computing, video production, as well as pure game machines of its times. Hardware expandability and modularity was designed into the architecture from start. The auto-configuration protocol, AUTOCONFIG, is an example of this (more on this later).
A set of on-board custom hardware chips were responsible for DMA-powered multimedia functionality including graphics, hardware sprites, memory copying, four channels of digital audio, and more.
Amiga 500 came as standard with memory configurations of 512KiB or 1024KiB. This memory resides on a memory bus which is shared between the main CPU and the Amiga custom chips. When the custom chips are heavily utilized, only a fraction of the memory bus time is available for the CPU to use. For more information on the Amiga architecture, see [1].

4

CHAPTER 1. INTRODUCTION | 5

## 1.2 GRETA Features

GRETA expansion board is a hardware expansion which connects to the expansion bus on the Amiga 500 computer and adds the following features to the system¹

### 8 MiB Fast RAM

The RAM is always available to the main CPU. There are no wait states involved so throughput is 3.4 MiB/s for a PAL Amiga 500. This also holds when the on-board peripherals described below are used. It is installed automatically in the system at boot by using the AUTOCONFIG protocol.

micro SD
A uSD flash memory controller is used for non-volatile storage. All accesses are performed by DMA to the 8 MiB Fast RAM. AUTOCONFIG together with custom device drivers loaded from the GRETA board is responsible for allowing booting from uSD memory.

Ethernet controller
A custom network controller that allows for 10/100MBit Ethernet networking. The network controller performs DMA to the 8 MiB Fast RAM.

External I/O
An external I/O pin header allows for use for dirverse use. For example a fast UART can be implemented. Another option is to use it as a debug port implementing the GDB Remote Serial protocol [2].

## 1.3 Expandability of GRETA

The GRETA expansion board can in principle be the basis of any peripheral suitable for the expansion bus of Amiga 500. For example a graphics or SATA adapter could be implemented by fitting the appropriate controller chip which is directed by the FPGA chip.
Also, with minor modification, the board can be made to fit the ZORRO II bus in Amiga 2000/3000/4000. It could in principle be achieved by modifying the physical connection and rerouting the AUTOCONFIG signals as appropriate.

## 1.4 Hardware overview

Figure 1.1 illustrates the hardware components constituting the GRETA expansion board. For more details, appendix A contains the electronic schematics the GRETA expansion board. The schematic files are also the hardware documentation. Everything needed to reproduce the hardware is included.
The PCB itself is routed on four layers with the following stack-up from top to bottom: Signal, ground, 3.3V, signal. Great care has been taken to achieve good signal integrity properties. For example, no bus signals or fast switching

1As of January 2014, only Fast RAM with AUTOCONFIG is implemented in HDL. Preparation for the other peripherals is done in terms of AUTOCONFIG and DMA access to the SDRAM. All the necessary hardware components are there aswell.

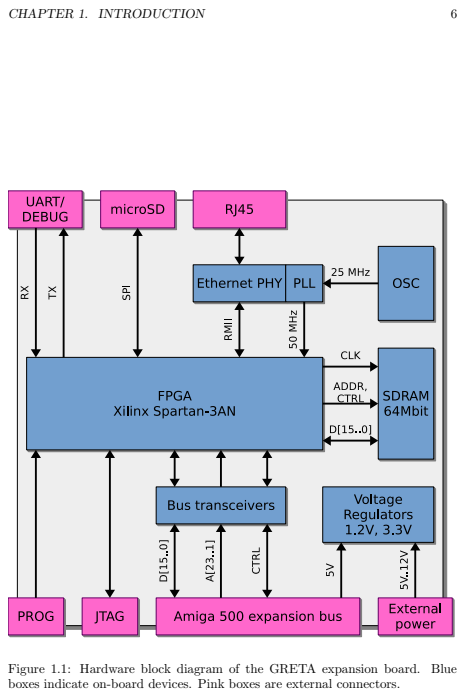
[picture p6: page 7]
CHAPTER 1. INTRODUCTION

Figure 1.1: Hardware block diagram of the GRETA expansion board. Blue
boxes indicate on-board devices. Pink boxes are external connectors.

CHAPTER 1. INTRODUCTION | 7

signals are routed through vias. Routing is tight; only two pins on the FPGA are unconnected.
All components, except for external connectors, are surface mounted. 0603 package is chosen for all resistors and most capacitors.
Figure 1.2 shows the PCB with components mounted and figure 1.3 the expansion board connected to the host computer. Figures 1.4 and 1.5 are images rendered from the Gerber files supplied to the PCB manufacturer.

### 1.4.1 Notes on the hardware design

The Amiga computer uses 5V TTL signals througout while the FPGA and the other GRETA components are rated at 3.3V and thus some signal level conversion is needed. The solution is to use 5V tolerant drivers for bidirectional signals and unidirectional signals from the computer to the expansion board. A 16-bit bidirectional transceiver, NXP 74LVCH162245A, a component with built-in 30 ohm series termination resistors, solves this. For signals going from the FPGA back to the computer, the device SN74LVC07A is used. It has TTL level tolerant open-drain outputs which fits well with the open collector inputs on the Amiga.
RMII is chosen over MII as Media Independen Interface for the Ethernet PHY. This reduces pin-count. As a bonus, the selected chip has a PLL that can feed the FPGA with a clock signal.

## 1.5 Tools

The following software tools have been used in the development of the GRETA hardware and HDL.

Arch Linux
Operating system, tools and infrastructure.

KiCad, build (2013-may-18)-stable
Schematic capture and PCB layout.

GNU Make
Dependecy tracking for compiling documentation and HDL code.

GHDL 0.30dev (20100112)
Functional simulation of HDL code.

Xilinx ISE 14.6
Development environment for Xilinx FPGA.

ASM-One V1.20
Macro-assembler and development environment for the Amiga computer.

Git
Revision control.

LibreOffice Draw
Vector graphics.

CHAPTER 1. INTRODUCTION | 8


Figure 1.2: Top side of GRETA expansion board. On the right edge is the connector to the Amiga computer expansion bus. The expansion connector has all its signals connected to three 16-bit transceivers and a 6-bit open drain driver.
Down to the left is the microSD card slot and above it the SDRAM. At top left is the RJ45 Ethernet connector and next to it the connector for external power. The large chip in the middle is the Xilinx FPGA. Above it are clock oscillator and Ethernet PHY.
Between the expansion connector and external power are two voltage regulators which generate 1.2V and 3.3V.

CHAPTER 1. INTRODUCTION | 9


Figure 1.3: The expansion board connects on the left side of the computer. The large chip parallel to the expansion is the Motorola MC68000 CPU.

VIM
Text editing.

LATEX
Typesetting text documents.

## 1.6 Errata

### 1.6.1 Deassert Ethernet PHY reset to get system clock

The clock input to the FPGA is driven by a PLL in the Ethernet PHY. For the Ethernet PHY to output the clock to the FPGA, the PHY reset input must be asserted. The PHY reset input is driven by the FPGA output designated PHY nRST.
Workaround: Always drive a high value on the FPGA output pin PHY nRST.

### 1.6.2 microSD pins are reversed

The pinout of the microSD socket does not match the PCB footprint. Workaround: Rotate the microSD connector 180◦ or correct the footprint.

CHAPTER 1. INTRODUCTION | 10


Figure 1.4: PCB top.

CHAPTER 1. INTRODUCTION | 11


Figure 1.5: PCB bottom.

# Chapter 2

# HDL Overview

This chapter gives an overview of the GRETA HDL architecture. All VHDL source files are included in appendix B. During the devolopment of the HDL components, a set of test benches were developed. These test benches are not included in the listings in this document. They are however provided in the GRETA file distribution.
The top-level module is contained in greta.vhdl with the port definition described in table 2.1. The VHDL package in file greta pkg.vhdl contains type definitions, address constants, bit constants and helper functions for the other HDL modules. Even though several custom types are used in the design, the top level ports only use types defined in IEEE.STD LOGIC 1164.
Figure 2.1 illustrates how the HDL components are related to each other. A clock synthesizer unit (DCM) in the FPGA is used to generate the 133 MHz clock which is used in the internal logic. It is commonly referred to as the clk signal.

## 2.1 AUTOCONFIG

According to the AUTOCONFIG protocol of the Amiga computer ZORRO II specification [1], a peripheral device can be in one of the states UNCONFIGURED, CONFIGURED or SHUT UP. After reset, every device is UNCONFIGURED and responds to bus accesses in the address space $E80000-$E8FFFF if its nCONFIG IN signal is asserted. The system software reads certain registers from the device in this area and eventually issues a write to relocate the device to another address space, typically somewhere inside $E90000-$EFFFFF or $200000-$9FFFFF depending on size requirements. The device is now CONFIGURED and passes its nCONFIG OUT signal to the next device’s nCONFIG IN. This procedure is repeated until all devices in the system are configured.
If the system for some reason choses not to configure a device, the device is forced into the SHUT UP state by writing to a dedicated register. In this state the device just passes on its nCONFIG OUT and must never respond again until the next reset.
The AUTOCONFIG space is the address area from $E80000-$EFFFFF. Inside this area there are eight equaly sized slots.

12

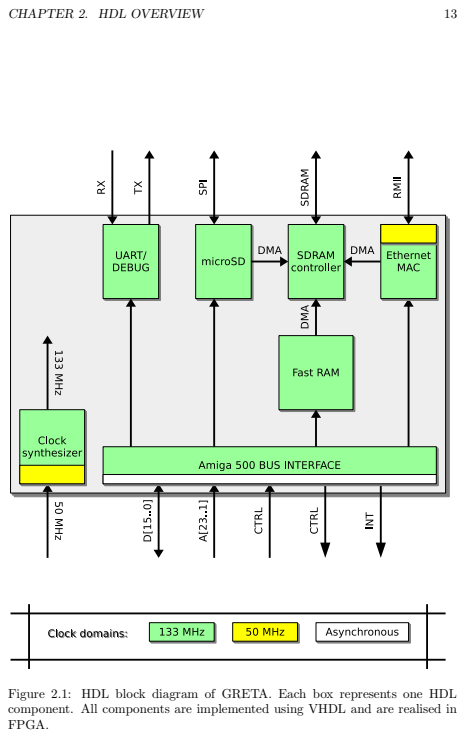
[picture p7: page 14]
CHAPTER 2. HDL OVERVIEW

Figure 2.1: HDL block diagram of GRETA. Each box represents one HDL
component. All components are implemented using VHDL and are realised in
FPGA.

CHAPTER 2. HDL OVERVIEW | 14
Port | Direction | Description
CLK25MHZ | in | If JP1 is open then this input is undefined.
| | Amiga 500 expansion bus
RL nRST | in | Reset
RL nAS | in | Address Strobe
RL nUDS | in | Data Upper Strobe
RL nLDS | in | Data Lower Strobe
RL RnW | in | Read/Write
RL CDAC | in | Amiga system clock with 90◦ phase offset
RL nOVR | out | Override internal generation of nDTACK
RL nINT2 | out | Amiga interrupt level 2
RL nINT6 | out | Amiga interrupt level 6
RL nINT7 | out | Non-maskable interrupt
RL nDTACK | out | Data Acknowledge
RL A[23:1] | in | Address bus
RL D[15:0] | inout | Bidirectinal data bus
RL D nOE | out | Output enable for data bus transceiver
RL D TO GRETA | out | Direction of data bus transceiver
| | SDRAM interface
SDRAM CLK | out | Clock
SDRAM CKE | out | Clock Enable
SDRAM nRAS | out | Row Address Strobe
SDRAM nCAS | out | Column Address Strobe
SDRAM nWE | out | Write Enable
SDRAM UDQM | out | Upper Data Input/Output Mask
SDRAM LDQM | out | Lower Data Input/Ouput Mask
SDRAM BA[1:0] | out | Bank Address
SDRAM A[11:0] | out | Address
SDRAM DQ[15:0] | inout | Data bus
| | microSD interface (SPI)
SPI CLK | out | Clock (SCLK)
SPI nCS | out | Chip Select (SS)
SPI DO | out | Data Output (MOSI)
SPI DI | in | Data Input (MISO)
| | Ethernet PHY (RMII)
PHY nRST | out | Reset
PHY MDC | out | MDIO Clock
PHY MDIO | inout | MDIO Data I/O
RMII REF CLK | in | RMII Clock (50 MHz)
RMII CRS DV | in | RMII Carrier Sense/Data Valid
RMII RXD[1:0] | in | RMII Receive Data
RMII TXD[1:0] | out | RMII Transmit Data
RMII TX EN | out | RMII Transmit Data Enable
| | UART/DEBUG interface
DEBUG RX | in
DEBUG TX | out

Table 2.1: GRETA top level ports.

CHAPTER 2. HDL OVERVIEW | 15

Definitions and helper functions for the AUTOCONFIG protocol can be found in the VHDL package autoconfig pkg.

# Chapter 3

# Bus interface

The bus decoder is responsible for decoding asynchronous MC68000 bus signals and exporting a synchronous read/write protocol to the GRETA peripherals.

## 3.1 Specification

The internal bus protocl is presented in table 3.1.
A pulse on req means that nwe, addr and wdata are valid and will remain so for at least 34 clk periods¹
Each GRETA peripheral device holds its rdata output valid as long as the peripheral is addressed, and zero otherwise. This allows for all GRETA peripherals to have their rdata outputs OR-wired to the bus interface rdata input. An addressed GRETA peripheral must respond to a read request in 34 clk periods² by asserting its dev select signal. The individual dev select signals are OR:ed together at the top level. The bus interface dev selected is used to determine if the bus transceivers shall drive data towards the Amiga.
The Amiga ZORRO II expansion bus protocol also defines the signal XRDY which can be used to delay individual bus accesses. XRDY is not used in the GRETA design and is not even connected to the GRETA hardware.

## 3.2 Implementation

All input signals from the Amiga expansion bus are synchronized before use in the GRETA clock domain. Control signals have two synchronizer stages. Stability of sampled data and address bus signals are assured by the control signals according to the MC68000 bus protocol. Furthermore, all inputs and outputs have their registers in the FPGA IO pads.

1To be decided. This is a safe minimum. 2To be decided. This is a safe minimum.

16

CHAPTER 3. BUS INTERFACE | 17
Port | Type | Direction | Description
clk | std logic | in | GRETA clock
cpu reset | std logic | out | Synchronous reset, activated by Amiga.
| | | Internal bus interface
req | std logic | out | Pulsed once for each 68000 read/write
nwe | bus nwe | out | Upper and lower byte select for write.
| | | ”11” means read.
addr | bus addr | out | Word destination for read and write transfers
wdata | bus data | out | WRITE data
rdata | bus data | in | READ data
dev select | std logic | in | An on-board peripheral is selected

Table 3.1: Bus interface, internal interface ports.

# Chapter 4

# SDRAM Controller

The SDRAM controller offers a user interface to a physical SDRAM chip. Design goals are to provide determinism and an easy to use control interface. Performance demands are set by client access requirements.
All timings in this chapter referes to a Hynix SDRAM chip clocked at 133 MHz and CAS latency of three.

## 4.1 Time resource estimations for SDRAM clients

The access time requirements for each SDRAM client presented in the previous chapter are presented in this section and summarised in Table 4.1.

### 4.1.1 Fast RAM Controller

For the ZORRO II bus interface on an NTSC Amiga 500, accesses can be performed at most once every fourth 7.16MHz clock cycle [3]. The bus read period and deadlines are derived from [3] and actual signal measurements.
Deadline for a bus read is limited by the time at which Motorola 68000 bus samples read data (falling edge leading to bus cycle state S7). For bus write, the deadline is effectively the time at which a following of bus read may occur. Requests from bus read and bus write can never be active at the same time
Client | Period | Execution time | Deadline
Fast RAM | 55 | 8 | 34
Disk | 85 | 8 | 85
MAC TX | 213 | 8 | 213
MAC RX | 213 | 8 | 213
Auto refresh | 2083 | 9 | 2083

Table 4.1: Real time requirements for clients issuing DMA operations on SDRAM. All time values are in units of 133 MHz clock periods, 7.5ns. Read and write execution times are based on single 16 bit word access with CAS latency of 3 cycles. Auto refresh is 9 cycles for this configuration.

18

CHAPTER 4. SDRAM CONTROLLER | 19

so they are combined to one task in Table 4.1 to simplify calculations. As a consequence of this, timing budget for the bus interface is a bit pessimistic.

### 4.1.2 Disk Controller

A bitrate of 25Mbit/s for Secure Digital over SPI gives a maximum throughput of 2.98MiB/s. The number of 7.5ns periods per 16bit SDRAM access is 85 ≤

16bit
25M bit/s ·

1
7.5ns

### 4.1.3 Ethernet MAC

Periods and deadlines for MAC RX and MAC TX are based on 10Mbit Ethernet in full-duplex mode. With the presented timing guarantees, only a very narrow FIFO buffer is required to transfer data between the Ethernet PHY clock domain and SDRAM.
The SDRAM access period time for a sustained transfer in each direction, expressed as 7.5ns periods, is 213 ≤

16bit
10M bit/s ·

1
7.5ns
If support for two word bursts is added to the SDRAM controller, then 100Mbit full-duplex can be supported without affecting the real time properties of the other RAM clients. (Though this is possible in theory, the Amiga 500 running a TCP/IP stack with SANA-II driver interface would never handle rates above 10Mbit anyway.)

### 4.1.4 Auto refresh

The SDRAM requires 64 refresh operation every 4096 ms. In terms of 7.5ns periods, this is 2083 ≤

64ms
4096 ·

1
7.5ns

## 4.2 SDRAM Scheduling

To solve the SDRAM scheduling problem, a static off-line approach is used. A time table is pre-calculated, in which each client has its dedicated time slot. An offset pointer iterates over the calendar slots. When the pointer has reached the end of the table it restarts from the top again.
This satisfies the goal of determinism and simplicity. Of course, it must be assured that each client will meet its deadline.
To simplify matters, the accessed bank is always precharged after an access. Furthermore, if a client does not issue a request in its designated time slot, the SDRAM will carry out an unused read operation anyway. Note that self refreshes are scheduled just as an ordinary client.
Also note that scheduling of requests to the SDRAM resource as presented in this section, will result in accesses not being served in the same time order as they were requested. Because of this, any of the peripherals must send its interrupt back to the computer only after an access has been acknowledged by the RAM arbiter. Anyhow, requests made by the same client will always be served in the same order as they were issued.
Table 4.2 illustrates the client calendar. The tightest timing budget is for a Disk request arriving at time 10 and finishes at time 89, resulting in a response time of 79 time units.

CHAPTER 4. SDRAM CONTROLLER | 20
Offset | Time | Client
0 | 0 - 8 | Fast RAM
1 | 9 - 17 | Disk
2 | 18 - 26 | Fast RAM
3 | 27 - 35 | MAC TX
4 | 36 - 44 | Fast RAM
5 | 45 - 53 | MAC RX
6 | 54 - 62 | Fast RAM
7 | 63 - 71 | Auto refresh
0 | 72 - 80 | Fast RAM
1 | 81 - 89 | Disk

Table 4.2: Calendar for static scheduling of the SDRAM resource. The unit of time offset is one period of a 133 MHz clock (7.5ns). Calendar has eight positions and repeats after offset 7.

Member | Type | Description
req | std logic | Assert high to issue an SDRAM request.
nwe | bus nwe | Upper and lower byte select for write.
"11" means read.
addr | bus addr | Target address for request.
wdata | bus data | Write data.

Table 4.3: Record type definition for ram bus. The type is used by SDRAM clients.

## 4.3 Specification

Each client communicates with the SDRAM controller using an in/out signal pair with types ram bus and std logic respectively. An example is the fast/fast ack pair. All clients share the read data bus rdata. See table 4.3 for a description of the ram bus record type.
Transfers are 16 bit wide but for write accesses, it is possible to select target bytes individually with the mask signal nwe.
To do an SDRAM request, the client sets its req signal high and holds it high until the corresponding ack signal goes high (pulse). The record members nwe, addr and wdata must be constant for the duration of asserted req. If it was a read request, then rdata is valid only in the same clock cycle as ack is pulsed.
Table 4.4 illustrates the internal HDL interface to the SDRAM controller.

CHAPTER 4. SDRAM CONTROLLER | 21
Port | Type | Direction | Description
clk | std logic | in | GRETA clock
reset | std logic | in | Synchronous reset
ready | std logic | out | Controller is ready for requests
| | | Fast RAM client
fast | ram bus | in | Control structure for accesses by Disk
fast ack | std logic | out | Acknowledge signal for Disk
| | | microSD client
disk | ram bus | in | Control structure for accesses by Disk
disk ack | std logic | out | Acknowledge signal for Disk
| | | Ethernet MAC client
mactx | ram bus | in | Control structure for accesses by MAC TX
mactx ack | std logic | out | Acknowledge signal for MAC TX
macrx | ram bus | in | Control structure for accesses by MAC RX
macrx ack | std logic | out | Acknowledge signal for MAC RX
| | | Common read data bus
rdata | bus data | out | Read data, only valid at the corresponding ack=1

Table 4.4: SDRAM component, interface for internal ports.

# Chapter 5

# Fast RAM Controller

The Fast RAM controller is responsible for implementing the AUTOCONFIG protol for configuring RAM at system start and then responds to Fast RAM accesses in the Amiga address range $200000-$9FFFFF.
This Amiga address range needs 23 bits to describe 16-bit word locations. This is a 16MiB range but only 8MiB in this range is used for accessing actual RAM. An important observation is that bit 23 is not significant for addressing to the SDRAM.
In fact, bit 23 can be ignored. This can be seen by splitting the Fast RAM address range into three parts and observe the mappings on SDRAM (table 5.1.

## 5.1 Specification

The HDL port interface of the Fast RAM component consists of the bus interface and the SDRAM interface as described above.

Amiga address | SDRAM address | Size
$200000-$3FFFFF (bit 23=0) | $200000-$9FFFFF | 2MiB
$400000-$7FFFFF (bit 23=0) | $400000-$7FFFFF | 4MiB
$800000-$9FFFFF (bit 23=1) | $000000-$1FFFFF | 2MiB

Table 5.1: Mapping of the external RAM in the Amiga address space to SDRAM address space.

22

# Chapter 6

# Disk Controller

## 6.1 Specification

### 6.1.1 User registers

## 6.2 Implementation

23

# Appendix A

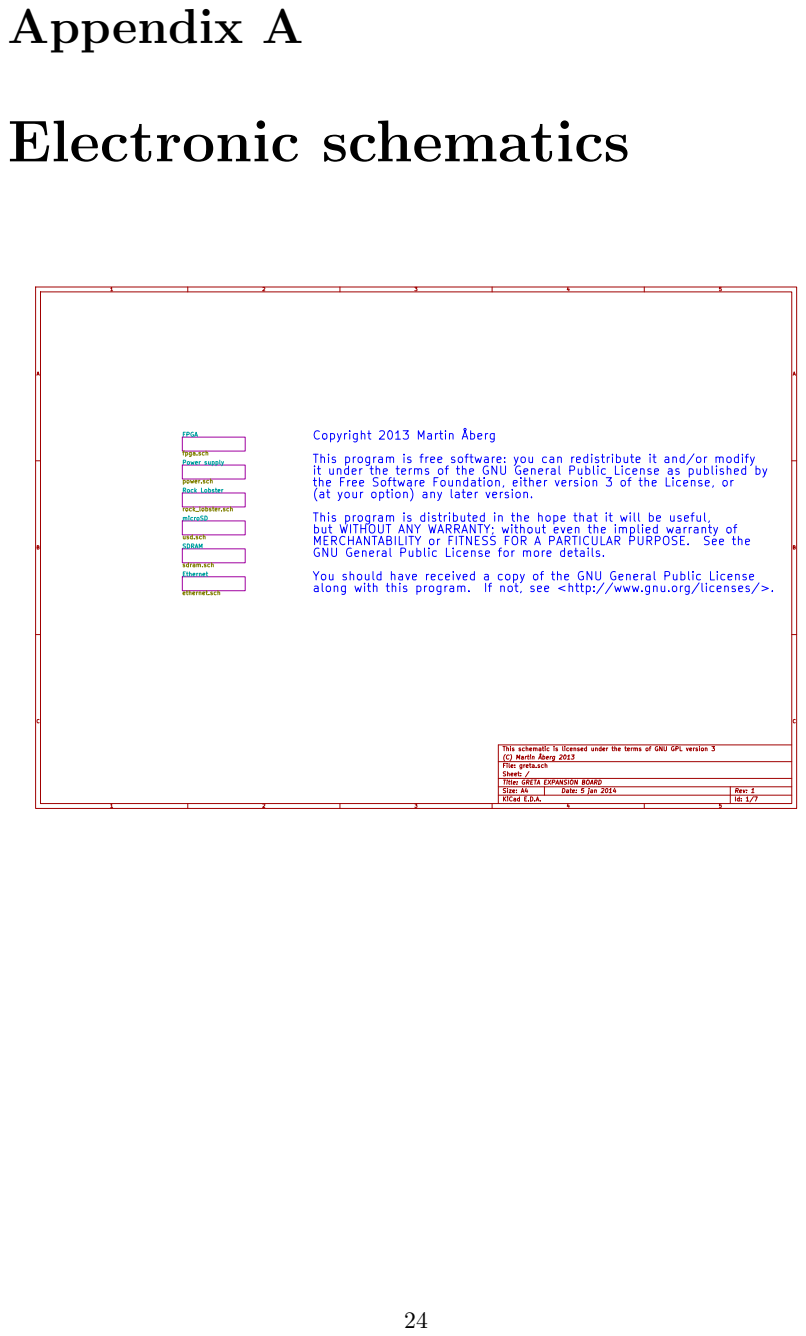
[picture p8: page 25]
Electronic schematics 1; C Date: 5 jan 2014; FPGA; fpga.sch Power supply

Copyright 2013 Martin Åberg
This program is free software: you can redistribute it and/or modify
it under the terms of the GNU General Public License as published by
the Free Software Foundation, either version 3 of the License, or
(at your option) any later version.
This program is distributed in the hope that it will be useful,
but WITHOUT ANY WARRANTY; without even the implied warranty of
MERCHANTABILITY or FITNESS FOR A PARTICULAR PURPOSE. See the
GNU General Public License for more details.
You should have received a copy of the GNU General Public License
along with this program. If not, see <http://www.gnu.org/licenses/>.

power.sch
usd.sch Rock Lobster

rock_lobster.sch
sdram.sch microSD

This schematic is licensed under the terms of GNU GPL version 3 Ethernet ethernet.sch SDRAM

(C) Martin Åberg 2013
File: greta.sch
Sheet: /
Title: GRETA EXPANSION BOARD

Size: A4 | Rev: 1
KiCad E.D.A. | Id: 1/7

IO_L03N_3 | 8 GND
IO_L03P_2/RDWR_B | 42 VCCINT 52

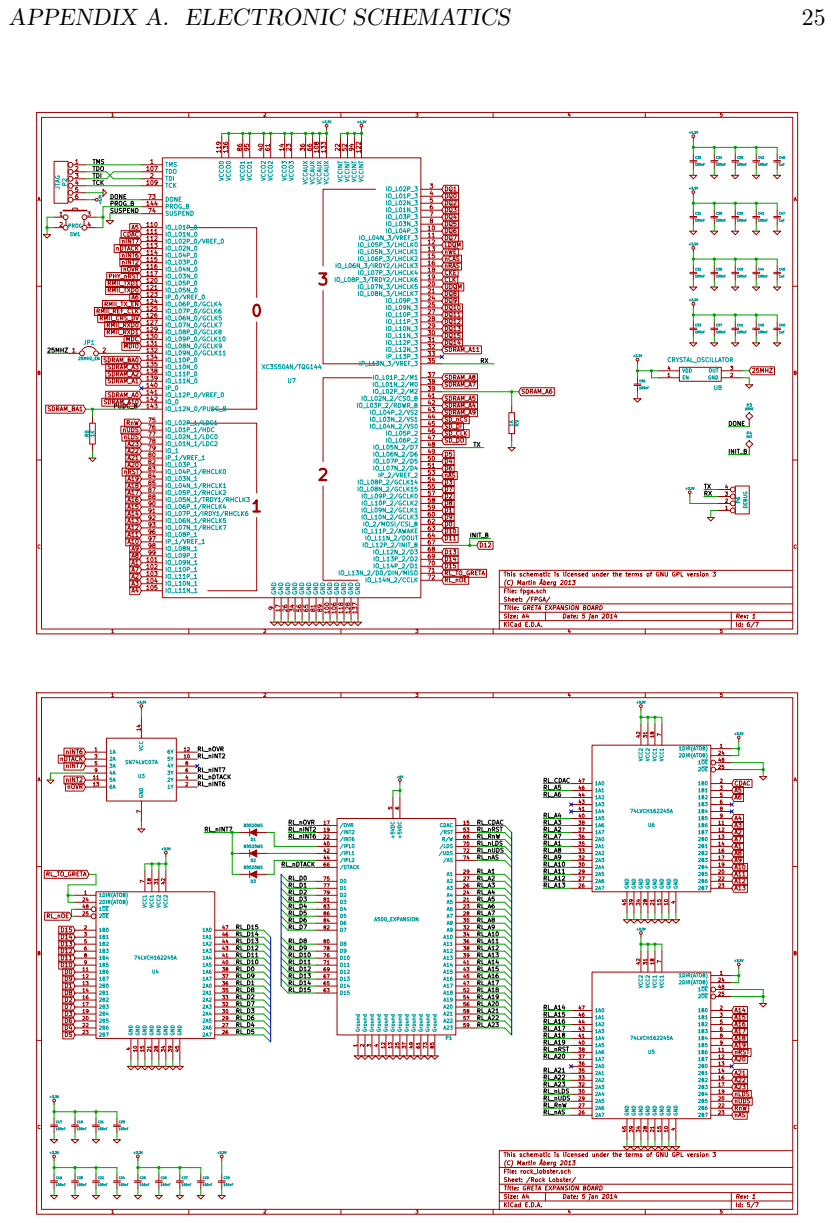
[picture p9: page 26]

This schematic is licensed under the terms of GNU GPL version 3
(C) Martin Åberg 2013
File: fpga.sch
Sheet: /FPGA/
Title: GRETA EXPANSION BOARD
KiCad E.D.A.

File: rock_lobster.sch
Sheet: /Rock Lobster/

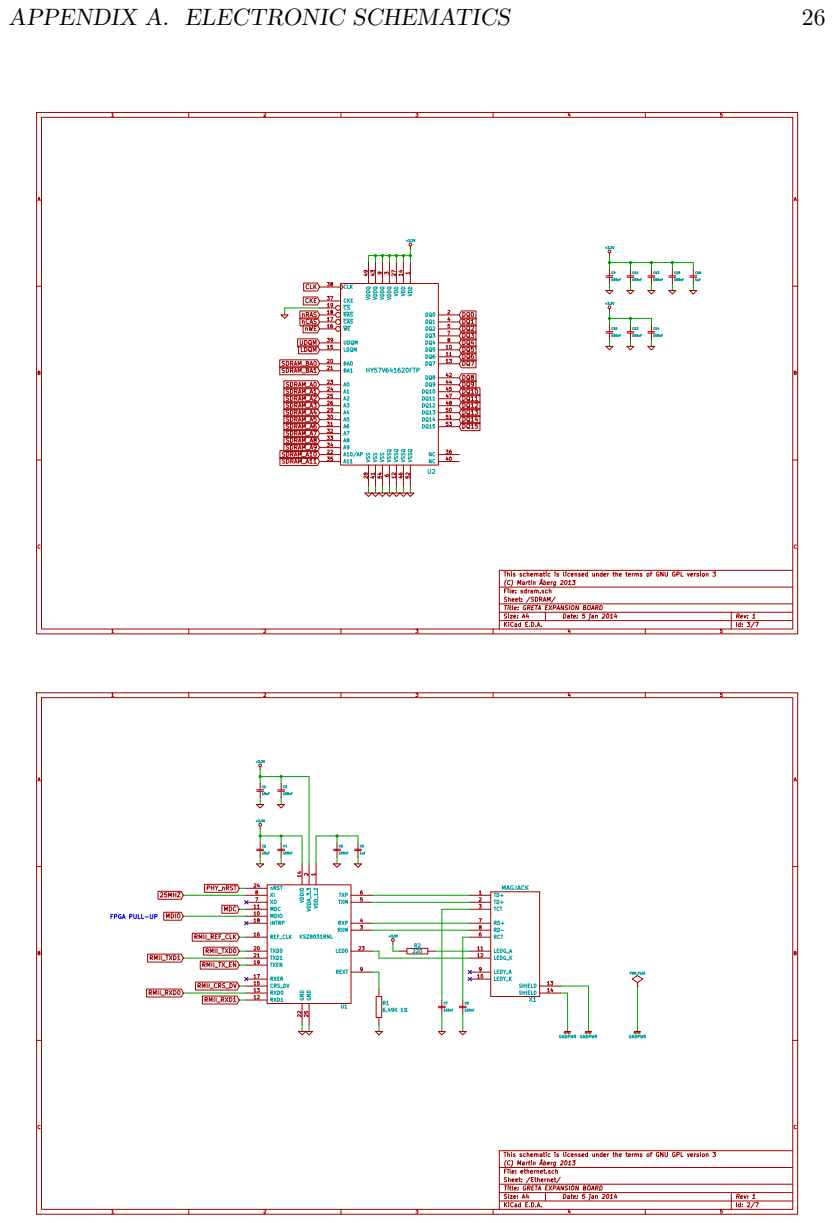
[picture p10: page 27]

9 DQ5 10 BA0 20 A5 30 NC 40 DQ13 50 DQ6 11 BA1 21 A6 31 VSS 41 DQ14 51 VSSQ 12 A10/AP 22 A7 32 DQ8 42 VSSQ 52 DQ7 13 A0 23 A8 33 VDDQ 43 DQ15 53 VDD 14 A1 24 A9 34 DQ9 44 VSS 54

This schematic is licensed under the terms of GNU GPL version 3
(C) Martin Åberg 2013
File: sdram.sch Sheet: /SDRAM/

Title: GRETA EXPANSION BOARD
KiCad E.D.A.

2 RXM 3 RXP 4 TXM 5 TXP 6 XO 7 XI 8 REXT 9 MDIO 10 TXD0 20 MDC 11 TXD1 21 RXD1 12 GND 22 RXD0 13

File: ethernet.sch Sheet: /Ethernet/

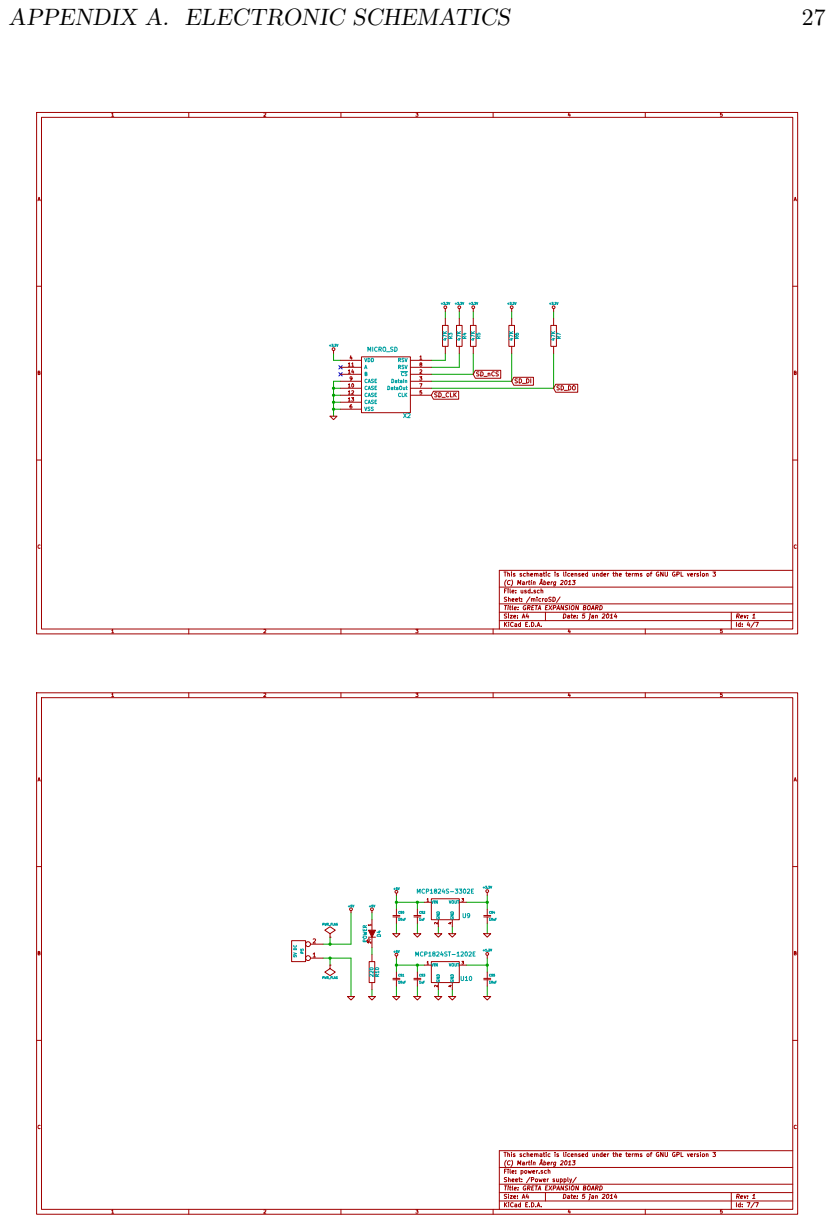
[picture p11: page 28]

This schematic is licensed under the terms of GNU GPL version 3
(C) Martin Åberg 2013
File: usd.sch Sheet: /microSD/

Title: GRETA EXPANSION BOARD
KiCad E.D.A.

File: power.sch
Sheet: /Power supply/

# Appendix B

# HDL code

## B.1 GRETA types, constants and functions

-- Copyright ( C ) 2013 , 2016 Martin ˚A berg
-- | This program is free software : you can redistribute it
-- | and / or modify it under the terms of the GNU General Public
-- | License as published by the Free Software Foundation ,
-- | either version 3 of the License , or ( at your option )
-- | any later version .
-- | This program is distributed in the hope that it will
-- | be useful , but WITHOUT ANY WARRANTY ; without even the
-- | implied warranty of M E R C H A N T A B I L I T Y or FITNESS FOR A
-- | PARTICULAR PURPOSE . | See the GNU General Public License
-- | for more details .
-- | You should have received a copy of the GNU General
-- | Public License along with this program . | If not , see
-- | < http :// www . gnu . org / licenses / >.

library ieee ;
use ieee . std_logic_1164 . all ;
use ieee . numeric_std . all ;

package greta_pkg is
subtype bus_addr | is std_logic_vector (23 downto | 1);
subtype bus_addr24 | is std_logic_vector (23 downto | 0);
subtype autoconfig_slot is std_logic_vector (18 downto 16);
subtype bus_data | is std_logic_vector (15 downto | 0);
subtype bus_data8 | is std_logic_vector ( 7 downto | 0);
subtype nibble | is std_logic_vector ( 3 downto | 0);

-- Auto - config space . Boards appear here before the system -- relocates them to their final address .
constant AUTOCONFIG_BASE | : bus_addr := x" E8_000 " & o" 0";
constant AUTOCONFIG_MASK | : bus_addr := x" F8_000 " & o" 0";
constant AUTOCONFIG_SLOT0 : autoconfig_slot := o" 0";

-- Because the Fast RAM area overlaps bit 23 , we split it -- into three separate areas .
constant FAST_RAM_BASE2 : bus_addr := x " 20 _000 " & o "0"; constant FAST_RAM_BASE4 : bus_addr := x " 40 _000 " & o "0"; constant FAST_RAM_BASE8 : bus_addr := x " 80 _000 " & o "0";

28

APPENDIX B. HDL CODE | 29

constant FAST_RAM_MASK2 : bus_addr := x " E0_000 " & o "0"; constant FAST_RAM_MASK4 : bus_addr := x " C0_000 " & o "0"; constant FAST_RAM_MASK8 : bus_addr := x " E0_000 " & o "0";

constant UPPER | : natural := 1;
constant LOWER | : natural := 0;

subtype bus_nwe is std_logic_vector ( UPPER downto LOWER );

constant WRITE_UPPER | : bus_nwe := ( UPPER => ’0’, LOWER => ’1 ’);
constant WRITE_LOWER | : bus_nwe := ( UPPER => ’1’, LOWER => ’0 ’);
constant WRITE_WORD | : bus_nwe := ( UPPER => ’0’ , LOWER => ’0 ’);
constant READ_WORD | : bus_nwe := ( UPPER = > ’1’, LOWER => ’1 ’);

-- Maximum number of GRETA bus slaves supported
constant NGSLAVES | : natural := 7;
subtype gslave | is natural range 0 to NGSLAVES -1;
subtype config_vector is std_logic_vector ( NGSLAVES -1 downto 0);

-- GRETA bus protocol
type gbus_in is record
reset | : std_logic ;
req | : std_logic ;
nwe | : bus_nwe ;
addr | : bus_addr ;
wdata | : bus_data ;
-- Active high AUTOCONFIG CONFIG_IN
config | : config_vector ;
end record ;
constant gbus_in_none : gbus_in := (
reset | => ’1 ’,
req | => ’0’,
nwe | => ( others => ’U ’) ,
addr | => ( others => ’U ’) ,
wdata | => ( others => ’U ’) ,
config | = > ( others = > ’0 ’)
);

type gbus_out is record
dev_select | : std_logic ;
rdata | : bus_data ;
interrupt | : std_logic ;
config | : std_logic ;
end record ;

-- SDRAM controller protocol type ram_bus is
record
req | : std_logic ;
nwe | : bus_nwe ;
addr | : bus_addr ;
wdata | : bus_data ;
end record ;

-- SPI
type spi_in is
record
miso : std_logic ;
end record ;

type spi_out is
record

APPENDIX B. HDL CODE | 30
clk | : std_logic ;
-- active high
mosi | : std_logic ;
ss | : std_logic ;
end record ;

-- Note that use of the e c _ B a s e A d d r e s s register is
-- tricky . The system will actually write twice . First -- the low order nybble is written to the e c _ B a s e A d d r e s s -- register +2 ( D15 - D12 ). Then the entire byte is written -- to e c _ B a s e A d d r e s s ( D15 - D8 ). This allows writing of a -- byte - wide address to nybble size registers .
constant ec_BaseAddress : natural := 16#48#;
constant ec_ShutUp | : natural := 16#4 C #;
constant FAST_PRODUCT_NUMBER | : std_logic_vector := x"1";
constant DISK_PRODUCT_NUMBER | : std_logic_vector := x"2";
constant ASPIC_PRODUCT_NUMBER : std_logic_vector := x "3";
constant ERT_ZORROII | : nibble := " 1100 ";
constant ERT_MEMLIST | : nibble := " 0010 ";
constant ERT_DIAGVALID | : nibble := " 0001 " ;
constant ERT_CHAINEDCONFIG | : nibble := " 1000 ";
constant ERT_MEMSIZE_8MB | : nibble := " 0000 ";
constant ERT_MEMSIZE_64K | : nibble := " 0001 ";
constant ERF_MEMSPACE | : nibble := " 1000 ";
constant ERF_NOSHUTUP | : nibble := " 0100 ";

-- A special " hacker " Manufacturer ID number is reserved -- for test use : 2011 ( $7DB ). When inverted this will look -- like $F824 .
constant HACKER_MANUFACTURER :
std_logic_vector (15 downto 0) := x " 07 DB ";

type expansionrom is array (0 to 63) of nibble ;

function is_autoconfig_reg (n : natural ; a : bus_addr ) return boolean ;

function is_autoconfig (a : bus_addr )
return boolean ;

function get_autoconfig_slot (a : bus_addr ) return autoconfig_slot ;

function is_fast_ram (a : bus_addr )
return boolean ;

end ;

package body greta_pkg is

function is_autoconfig_reg (n : natural ; a : bus_addr ) return boolean is
variable reg_addr : std_logic_vector (6 downto 0);
begin
reg_addr := std_logic_vector ( to_unsigned (n , reg_addr ’ length )); return reg_addr (6 downto 1) = a (6 downto 1);
end ;

function is_autoconfig (a : bus_addr )

APPENDIX B. HDL CODE | 31

return boolean is
begin
return (a and AUTOCONFIG_MASK ) = AUTOCONFIG_BASE ; end ;

function get_autoconfig_slot (a : bus_addr )
return autoconfig_slot is
begin
return a( autoconfig_slot ’ range );
end ;

function is_fast_ram (a : bus_addr ) return boolean is
begin
return (
(( a and FAST_RAM_MASK2 ) = FAST_RAM_BASE2 ) or (( a and FAST_RAM_MASK4 ) = FAST_RAM_BASE4 ) or (( a and FAST_RAM_MASK8 ) = FAST_RAM_BASE8 ) );
end ;

end ;

APPENDIX B. HDL CODE | 32
B.2 | GRETA

-- Copyright ( C ) 2013 , 2016 Martin ˚A berg
-- | This program is free software : you can redistribute it
-- | and / or modify it under the terms of the GNU General Public
-- | License as published by the Free Software Foundation ,
-- | either version 3 of the License , or ( at your option )
-- | any later version .
-- | This program is distributed in the hope that it will
-- | be useful , but WITHOUT ANY WARRANTY ; without even the
-- | implied warranty of M E R C H A N T A B I L I T Y or FITNESS FOR A
-- | PARTICULAR PURPOSE . | See the GNU General Public License
-- | for more details .
-- | You should have received a copy of the GNU General
-- | Public License along with this program . | If not , see
-- | < http :// www . gnu . org / licenses / >.

library ieee ;
use ieee . std_logic_1164 . all ;
use work . greta_pkg . all ;

entity greta is
port (
-- - EXTERNAL CLOCK
CLK25MHZ | : in | std_logic ;

-- - ROCK LOBSTER
RL_nRST | : in | std_logic ;
RL_nAS | : in | std_logic ;
RL_nUDS | : in | std_logic ;
RL_nLDS | : in | std_logic ;
RL_RnW | : in | std_logic ;
RL_CDAC | : in | std_logic ;
RL_nOVR | : out | std_logic ;
RL_nINT2 | : out | std_logic ;
RL_nINT6 | : out | std_logic ;
RL_nINT7 | : out | std_logic ;
RL_nDTACK | : out | std_logic ;
RL_A | : in | std_logic_vector (23 downto 1);
RL_D | : inout std_logic_vector (15 downto 0);
RL_D_nOE | : out | std_logic ;
RL_D_TO_GRETA | : out | std_logic ;

-- - SDRAM
SDRAM_CLK | : out | std_logic ;
SDRAM_CKE | : out | std_logic ;
SDRAM_nRAS | : out | std_logic ;
SDRAM_nCAS | : out | std_logic ;
SDRAM_nWE | : out | std_logic ;
SDRAM_UDQM | : out | std_logic ;
SDRAM_LDQM | : out | std_logic ;
SDRAM_BA | : out | std_logic_vector (1 downto 0);
SDRAM_A | : out | std_logic_vector (11 downto 0);
SDRAM_DQ | : inout std_logic_vector (15 downto 0);

-- - SECURE DIGITAL ( SPI )
SPI_CLK | : out | std_logic ;
SPI_nCS | : out | std_logic ;
SPI_DI | : out | std_logic ;

APPENDIX B. HDL CODE | 33
SPI_DO | : in | std_logic ;

-- - ETHERNET PHY ( RMII )
PHY_nRST | : out | std_logic ;
PHY_MDC | : out | std_logic ;
PHY_MDIO | : inout std_logic ;
RMII_REF_CLK | : in | std_logic ;
RMII_CRS_DV | : in | std_logic ;
RMII_RXD | : in | std_logic_vector (1 downto 0);
RMII_TXD | : in | std_logic_vector (1 downto 0);
RMII_TX_EN | : out | std_logic ;

-- - UART / DEBUG
DEBUG_RX | : in | std_logic ;
DEBUG_TX | : out | std_logic
);
end ;

architecture structural of greta is
signal clk | | : std_logic ;
signal clk180 | | : std_logic ;
signal cpu_reset | | : std_logic ;
signal dcm_locked | | : std_logic ;
signal req | | : std_logic ;
signal nwe | | : bus_nwe ;
signal addr | | : bus_addr ;
signal wdata | | : bus_data ;
signal rdata | | : bus_data ;
signal fast_select | | : std_logic ;
signal fast_rdata | | : bus_data ;
signal fast_config_in | : std_logic ;
signal fast_config_out | : std_logic ;
signal sdram_rdata | | : bus_data ;
signal sdram_fast | | : ram_bus := (
req => ’0’,
nwe => READ_WORD ,
addr = > ( others = > ’0 ’) ,
wdata => ( others => ’0 ’)
);
signal sdram_fast_ack | : std_logic := ’0 ’;
signal disk_select | | : std_logic ;
signal disk_rdata | | : bus_data ;
signal disk_config_in | : std_logic ;
signal disk_config_out | : std_logic ;
signal sdram_disk | | : ram_bus := (
req => ’0’,
nwe => READ_WORD ,
addr = > ( others = > ’0 ’) ,
wdata => ( others => ’0 ’)
);
signal sdram_disk_ack | : std_logic := ’0 ’;
signal dev_select | | : std_logic ;
signal gbi | : gbus_in ;
signal gbo_aspic | : gbus_out ;

APPENDIX B. HDL CODE | 34

signal spii : spi_in ;
signal spio : spi_out ;
constant GSLAVE_FAST | : gslave := 0;
constant GSLAVE_DISK | : gslave := 1;
constant GSLAVE_ASPIC : gslave := 2;
constant GSLAVE_LAST : gslave := GSLAVE_ASPIC ; begin

-- debug outputs
DEBUG_TX <= gbo_aspic . config ;

-- GRETA bus connections
dev_select <= fast_select or disk_select or gbo_aspic . dev_select ; fast_config_in <= ’1 ’;
disk_config_in <= fast_config_out ;
gbi . config ( GSLAVE_ASPIC ) <= disk_config_out ;

rdata <= fast_rdata or disk_rdata or gbo_aspic . rdata ;

gbi . reset | <= cpu_reset ;
gbi . req | <= req ;
gbi . nwe | <= nwe ;
gbi . addr | <= addr ;
gbi . wdata | <= wdata ;

SPI_CLK <= spio . clk ;
SPI_nCS <= spio . ss ;
SPI_DI <= spio . mosi ;
spii . miso <= SPI_DO ;

-- Enable PLL .
PHY_nRST <= ’1 ’;
PHY_MDC <= ’Z ’;
RMII_TX_EN <= ’0 ’;

RL_nINT2 <= not gbo_aspic . interrupt ;

-- Generate 133.3 MHz clock from 50 MHz PHY clock . dcm_0 : entity work . dcm_greta
port map (
CLKIN_IN | => RMII_REF_CLK ,
CLKFX_OUT | => clk ,
CLKFX180_OUT | => clk180 ,
CLKIN_IBUFG_OUT => open ,
LOCKED_OUT | => dcm_locked
);

-- SDRAM clock output uses a DDR output buffer . See Xilinx -- do cu me nt at io n for generic and port descriptions . ODDR2_inst : ODDR2
generic map (
DDR_ALIGNMENT => " NONE " ,
INIT = > ’0’,
SRTYPE => " SYNC ")
port map (
Q | => SDRAM_CLK ,
C0 | => clk ,
C1 | => clk180 ,
CE | => ’1’,
D0 | => ’0’,
D1 | => ’1’,

APPENDIX B. HDL CODE | 35
R | => ’0’,
S | => ’0’
);

bus_interface_0 : entity work . bus_interface port map (
clk | => clk ,
cpu_reset | => cpu_reset ,
dcm_locked | => dcm_locked ,
dev_select | => dev_select ,
req | => req ,
nwe | => nwe ,
addr | => addr ,
wdata | = > wdata ,
rdata | = > rdata ,

-- - ROCK LOBSTER
nRST | => RL_nRST ,
nAS | => RL_nAS ,
nUDS | => RL_nUDS ,
nLDS | => RL_nLDS ,
RnW | => RL_RnW ,
CDAC | => RL_CDAC ,
nOVR | => RL_nOVR ,
nINT2 | = > open ,
nINT6 | = > RL_nINT6 ,
nINT7 | = > RL_nINT7 ,
nDTACK | = > RL_nDTACK ,
A | => RL_A ,
D | => RL_D ,
D_nOE | = > RL_D_nOE ,
D_TO_GRETA | => RL_D_TO_GRETA
);

sdram_0 : entity work . sdram
port map (
clk | => clk ,
reset | = > cpu_reset ,
ready | = > open ,

-- - CLIENTS
disk | => sdram_disk ,
disk_ack | => sdram_disk_ack ,
fast | => sdram_fast ,
fast_ack | => sdram_fast_ack ,
rdata | = > sdram_rdata ,

-- - SDRAM
SDRAM_CKE | => SDRAM_CKE ,
SDRAM_nRAS | => SDRAM_nRAS ,
SDRAM_nCAS | => SDRAM_nCAS ,
SDRAM_nWE | => SDRAM_nWE ,
SDRAM_UDQM | => SDRAM_UDQM ,
SDRAM_LDQM | => SDRAM_LDQM ,
SDRAM_BA | => SDRAM_BA ,
SDRAM_A | = > SDRAM_A ,
SDRAM_DQ | => SDRAM_DQ
);

fast_0 : entity work . fast port map (

APPENDIX B. HDL CODE | 36
clk | => clk ,
reset | => cpu_reset ,
req | => req ,
nwe | => nwe ,
dev_select | => fast_select ,
addr | => addr ,
wdata | => wdata ,
rdata | => fast_rdata ,
config_in | => fast_config_in ,
config_out | => fast_config_out ,
ram | => sdram_fast ,
ram_ack | => sdram_fast_ack ,
ram_rdata | => sdram_rdata
);

disk_0 : entity work . disk port map (
clk | => clk ,
reset | => cpu_reset ,
req | => req ,
nwe | => nwe ,
dev_select | => disk_select ,
addr | => addr ,
wdata | => wdata ,
rdata | => disk_rdata ,
config_in | => disk_config_in ,
config_out | => disk_config_out ,
ram | => sdram_disk ,
ram_ack | => sdram_disk_ack ,
ram_rdata | => sdram_rdata ,
SPI_CLK | => open ,
SPI_nCS | => open ,
SPI_DO | = > open ,
SPI_DI | = > ’0’
);

-- ASPIC - SPI controller for GRETA aspic_0 : entity work . aspic generic map (
gslave | = > GSLAVE_ASPIC ,
dwidth | = > 8 ,
swidth | = > 8 ,
sspol | => ’0 ’
)
port map (
clk | => clk ,
gbi | => gbi ,
gbo | => gbo_aspic ,
spii | => spii ,
spio | => spio
);

end ;

APPENDIX B. HDL CODE | 37
B.3 | Bus Interface
-- Copyright ( C ) 2013 Martin ˚A berg
-- | This program is free software : you can redistribute it
-- | and / or modify it under the terms of the GNU General Public
-- | License as published by the Free Software Foundation ,
-- | either version 3 of the License , or ( at your option )
-- | any later version .
-- | This program is distributed in the hope that it will
-- | be useful , but WITHOUT ANY WARRANTY ; without even the
-- | implied warranty of M E R C H A N T A B I L I T Y or FITNESS FOR A
-- | PARTICULAR PURPOSE . | See the GNU General Public License
-- | for more details .
-- | You should have received a copy of the GNU General
-- | Public License along with this program . | If not , see
-- | < http :// www . gnu . org / licenses / >.

-- This component is responsible for translating asynchronous -- MC68000 bus accesses to a protocol suitable for the
-- AUTOCONFIG component and the other upstream components . library ieee ;
use ieee . std_logic_1164 . all ;
use work . greta_pkg . all ;

entity bus_interface is
port (
-- - GRETA
clk | : in | std_logic ;
cpu_reset | : out | std_logic ;
dcm_locked | : in | std_logic ;
req | : out | std_logic ;
nwe | : out | bus_nwe ;
addr | : out | bus_addr ;
wdata | : out | bus_data ;
rdata | : in | bus_data ;
dev_select | : in | std_logic ;
-- - ROCK LOBSTER
nRST | : in | std_logic ;
nAS | : in | std_logic ;
nUDS | : in | std_logic ;
nLDS | : in | std_logic ;
RnW | : in | std_logic ;
CDAC | : in | std_logic ;
nOVR | : out | std_logic ;
nINT2 | : out | std_logic ;
nINT6 | : out | std_logic ;
nINT7 | : out | std_logic ;
nDTACK | : out | std_logic ;
A | : in | bus_addr ;
D | : inout bus_data ;
D_nOE | : out | std_logic := ’1 ’;
D_TO_GRETA | : out | std_logic := ’1 ’
);
end ;

architecture rtl of bus_interface is
signal nRST_sync | : std_logic_vector (1 downto 0) := " 00 ";

APPENDIX B. HDL CODE | 38
signal nAS_sync | : std_logic_vector (1 downto 0) := " 11 ";
signal nUDS_sync | : std_logic_vector (2 downto 0);
signal nLDS_sync | : std_logic_vector (2 downto 0);
signal RnW_sync | : std_logic_vector (1 downto 0);

signal cpu_reset_int : std_logic := ’1 ’;

type bus_state is (S1 , W1 , W2 , R1 ); signal state : bus_state := S1 ;

begin

synchronizers : process ( clk )
begin
if rising_edge ( clk ) then
nRST_sync | <= nRST_sync (0) & nRST ;
nAS_sync | <= nAS_sync (0) & nAS ;
RnW_sync | <= RnW_sync (0) & RnW ;
nUDS_sync | <= nUDS_sync (1 downto 0) & nUDS ;
nLDS_sync | <= nLDS_sync (1 downto 0) & nLDS ;
wdata | <= D;
addr | <= A;

-- NOTE : clk may be in any state , so the following logic -- may get trashed ...
if ( dcm_locked = ’1 ’) and ( nRST_sync (1) = ’1 ’) then cpu_reset_int <= ’0 ’;
else
cpu_reset_int <= ’1 ’;
end if ;
end if ;
end process ;

process ( clk )
begin
if rising_edge ( clk ) then
if cpu_reset_int = ’1 ’ then
D_nOE | <= ’1 ’;
D_TO_GRETA | <= ’1 ’;
req <= ’0 ’;
state <= S1 ;
else
D_nOE | <= ’1 ’;
D_TO_GRETA | <= ’1 ’;
req <= ’0 ’;
D <= " ZZZZZZZZZZZZZZZZ " ;

case state is
when S1 = >
if nAS_sync (1) = ’0’ then
-- Transfer
if ( RnW_sync (1) = ’0 ’) then -- Write
state <= W1 ;
else
-- Read , wait for nUDS and nLDS to become stable . if ( nUDS_sync (1) = ’0 ’) or ( nLDS_sync (1) = ’0 ’) then req <= ’1 ’;
nwe <= READ_WORD ;
D_TO_GRETA <= ’0 ’;
state <= R1 ;

APPENDIX B. HDL CODE | 39

end if ;
end if ;
end if ;

when R1 = >
D_TO_GRETA <= ’0 ’;
D_nOE <= not dev_select ;
D <= rdata ;
if ( nUDS_sync (1) = ’1 ’) and ( nLDS_sync (1) = ’1 ’) then state <= S1 ;
D_nOE <= ’1 ’;
D <= " ZZZZZZZZZZZZZZZZ " ;
end if ;

when W1 = >
D_nOE <= ’0 ’;
-- Wait for nUDS and nLDS to become stable .
if (( nUDS_sync (2) = nUDS_sync (1))) and
(( nLDS_sync (2) = nLDS_sync (1))) and
(( nUDS_sync (2) = ’0 ’) or ( nLDS_sync (2) = ’0 ’)) then nwe <= nUDS_sync (1) & nLDS_sync (1);
req <= ’1 ’;
-- wdata and addr is driven elsewhere .
state <= W2 ;
end if ;

when W2 = >
D_nOE <= ’0 ’;
if nAS_sync (1) = ’1’ then D_nOE <= ’1 ’;
state <= S1 ;
end if ;

end case ;

end if ;
end if ;
end process ;

cpu_reset <= cpu_reset_int ;

nOVR | <= ’1 ’;
nINT2 | <= ’1 ’;
nINT6 | <= ’1 ’;
nINT7 | <= ’1 ’;
nDTACK | <= ’1 ’;

end ;

APPENDIX B. HDL CODE | 40
B.4 | SDRAM Controller
-- Copyright ( C ) 2013 Martin ˚A berg
-- | This program is free software : you can redistribute it
-- | and / or modify it under the terms of the GNU General Public
-- | License as published by the Free Software Foundation ,
-- | either version 3 of the License , or ( at your option )
-- | any later version .
-- | This program is distributed in the hope that it will
-- | be useful , but WITHOUT ANY WARRANTY ; without even the
-- | implied warranty of M E R C H A N T A B I L I T Y or FITNESS FOR A
-- | PARTICULAR PURPOSE . | See the GNU General Public License
-- | for more details .
-- | You should have received a copy of the GNU General
-- | Public License along with this program . | If not , see
-- | < http :// www . gnu . org / licenses / >.

-- RAM arbiter and controller library ieee ;
use ieee . std_logic_1164 . all ; use ieee . numeric_std . all ; use work . greta_pkg . all ;

entity sdram is
port (
clk | : in | std_logic ;
reset | : in | std_logic ;
ready | : out | std_logic := ’0 ’;

-- - CLIENTS
fast | : in | ram_bus ;
fast_ack | : out | std_logic ;
disk | : in | ram_bus ;
disk_ack | : out | std_logic ;
rdata | : out | bus_data ;

-- - SDRAM
SDRAM_CKE | : out | std_logic ;
SDRAM_nRAS | : out | std_logic ;
SDRAM_nCAS | : out | std_logic ;
SDRAM_nWE | : out | std_logic ;
SDRAM_UDQM | : out | std_logic ;
SDRAM_LDQM | : out | std_logic ;
SDRAM_BA | : out | std_logic_vector ( 1 downto | 0);
SDRAM_A | : out | std_logic_vector (11 downto | 0);
SDRAM_DQ | : inout std_logic_vector (15 downto | 0) :=
( others => ’Z ’)
);
end ;

architecture rtl of sdram is constant NCLIENTS : integer := 2;
constant AP : integer := 10;

subtype init_counter_t is unsigned (14 downto 0);
signal init_counter : init_counter_t := ( others => ’0 ’);

APPENDIX B. HDL CODE | 41

subtype tick_t is unsigned (3 downto 0); signal tick : tick_t := ( others => ’0 ’);

subtype offset_t is unsigned (1 downto 0);
signal offset : offset_t := ( others => ’0 ’);

type state_t is ( INIT_NOP , INIT_PRE , INIT_AR , INIT_MRS , INIT_DONE );
signal state : state_t := INIT_NOP ;
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

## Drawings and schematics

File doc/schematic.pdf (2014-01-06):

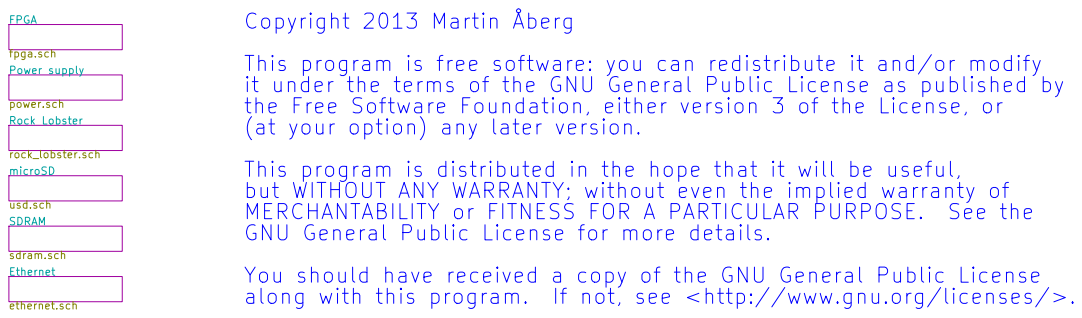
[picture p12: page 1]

Copyright 2013 Martin Åberg
This program is free software: you can redistribute it and/or modify
it under the terms of the GNU General Public License as published by
the Free Software Foundation, either version 3 of the License, or
(at your option) any later version.
This program is distributed in the hope that it will be useful,
but WITHOUT ANY WARRANTY; without even the implied warranty of
MERCHANTABILITY or FITNESS FOR A PARTICULAR PURPOSE. See the
GNU General Public License for more details.
You should have received a copy of the GNU General Public License

power.sch
usd.sch Rock Lobster

This schematic is licensed under the terms of GNU GPL version 3 Ethernet ethernet.sch SDRAM

(C) Martin Åberg 2013
File: greta.sch
Sheet: /
Title: GRETA EXPANSION BOARD
KiCad E.D.A.

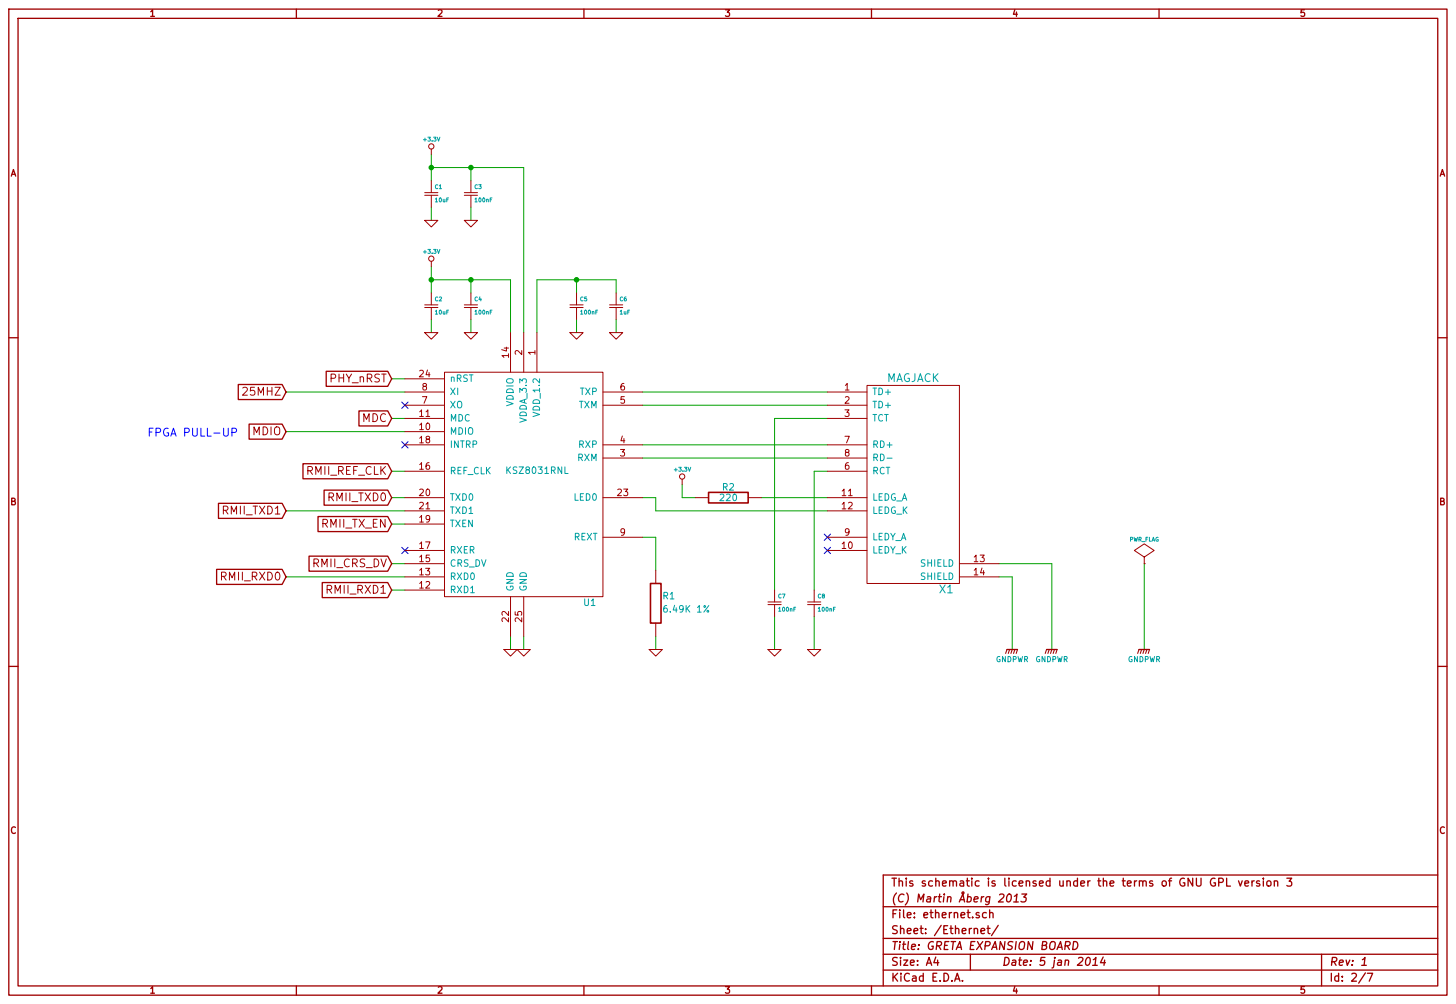
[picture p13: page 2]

2 RXM 3 RXP 4 TXM 5 TXP 6 XO 7 XI 8 REXT 9 MDIO 10 TXD0 20 MDC 11 TXD1 21 RXD1 12 GND 22 RXD0 13

This schematic is licensed under the terms of GNU GPL version 3
(C) Martin Åberg 2013
File: ethernet.sch Sheet: /Ethernet/

Title: GRETA EXPANSION BOARD

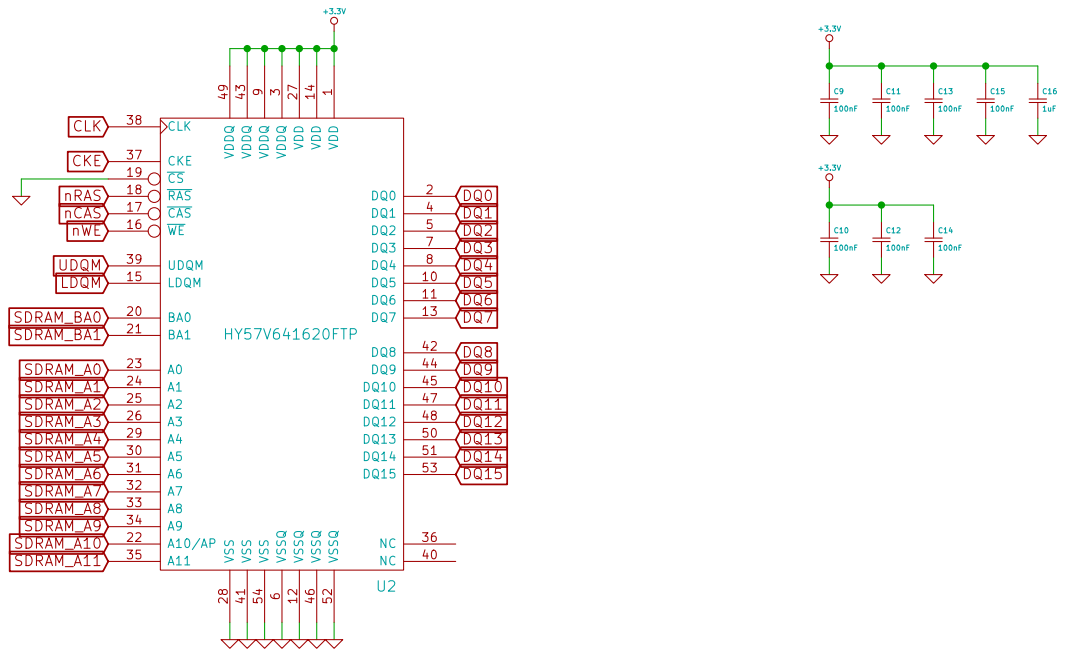
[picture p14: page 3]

9 DQ5 10 BA0 20 A5 30 NC 40 DQ13 50 DQ6 11 BA1 21 A6 31 VSS 41 DQ14 51 VSSQ 12 A10/AP 22 A7 32 DQ8 42 VSSQ 52 DQ7 13 A0 23 A8 33 VDDQ 43 DQ15 53 VDD 14 A1 24 A9 34 DQ9 44 VSS 54

This schematic is licensed under the terms of GNU GPL version 3
(C) Martin Åberg 2013
File: sdram.sch Sheet: /SDRAM/

Title: GRETA EXPANSION BOARD

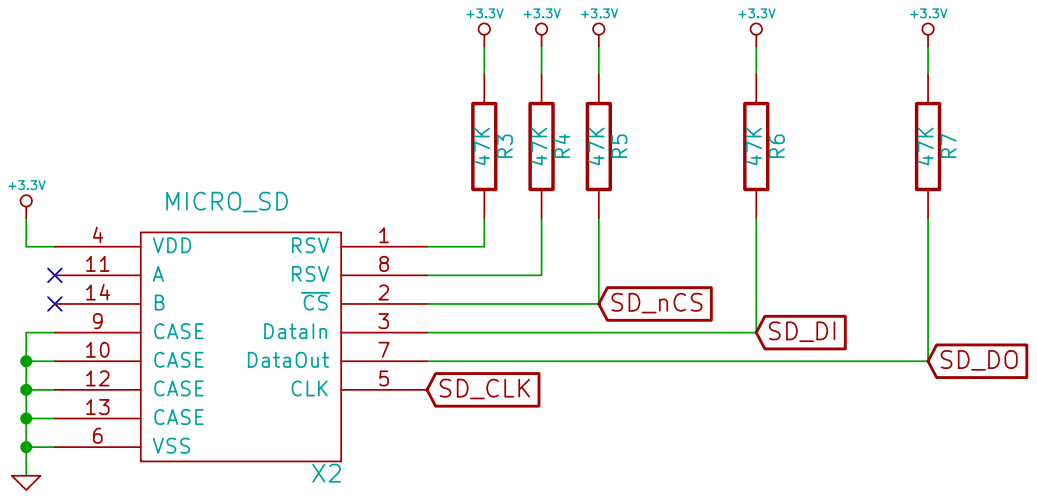
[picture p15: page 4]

This schematic is licensed under the terms of GNU GPL version 3
(C) Martin Åberg 2013
File: usd.sch Sheet: /microSD/

Title: GRETA EXPANSION BOARD

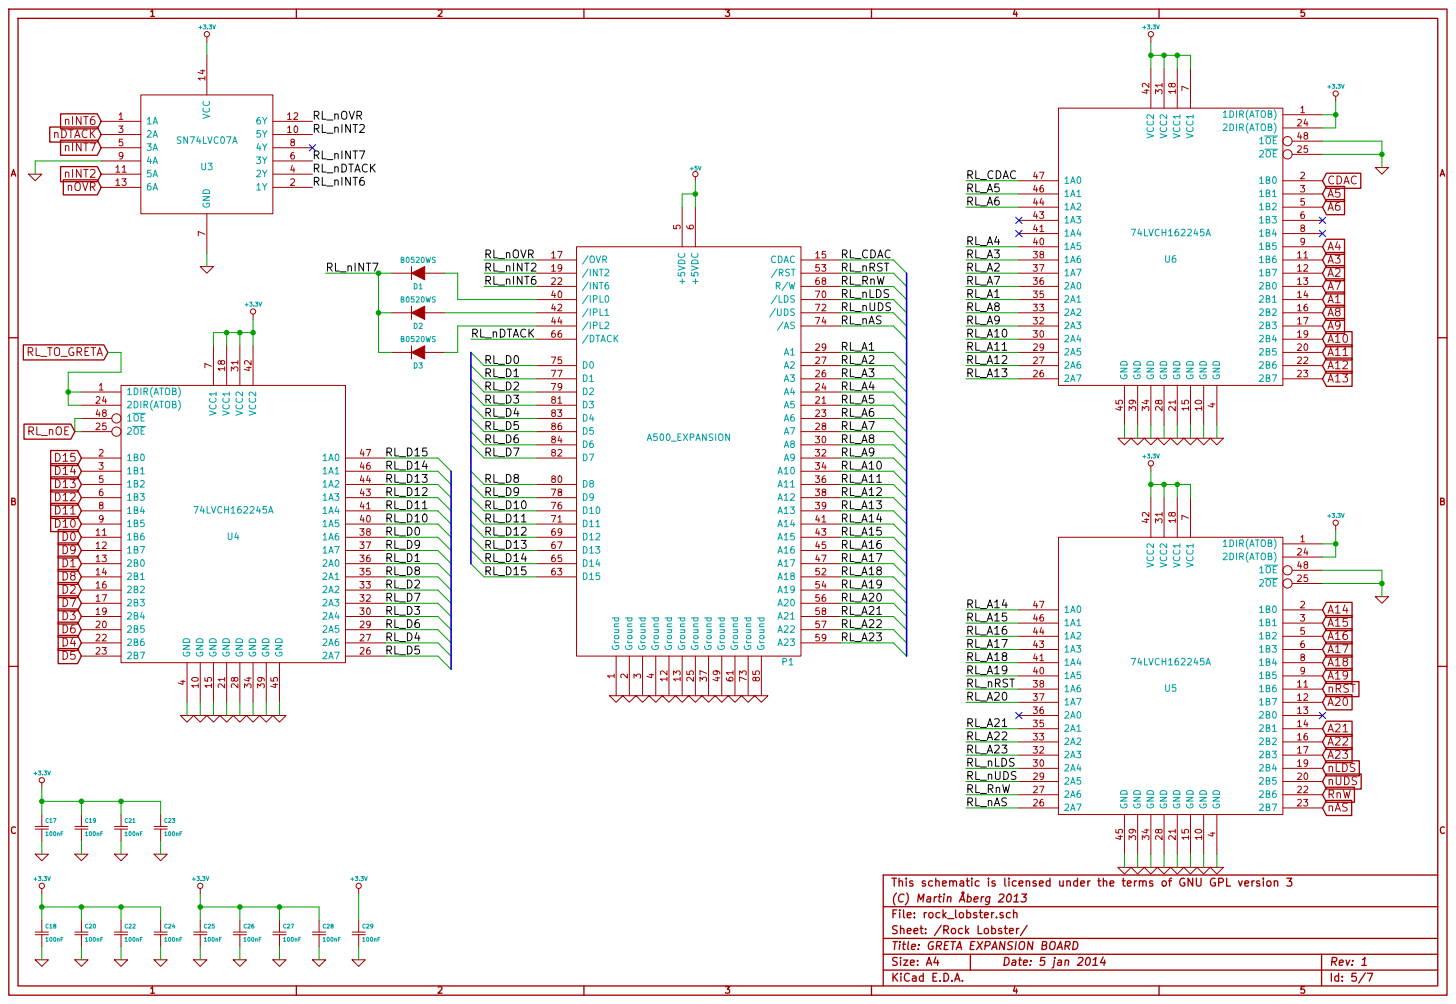
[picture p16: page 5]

This schematic is licensed under the terms of GNU GPL version 3
(C) Martin Åberg 2013
File: rock_lobster.sch
Sheet: /Rock Lobster/
Title: GRETA EXPANSION BOARD

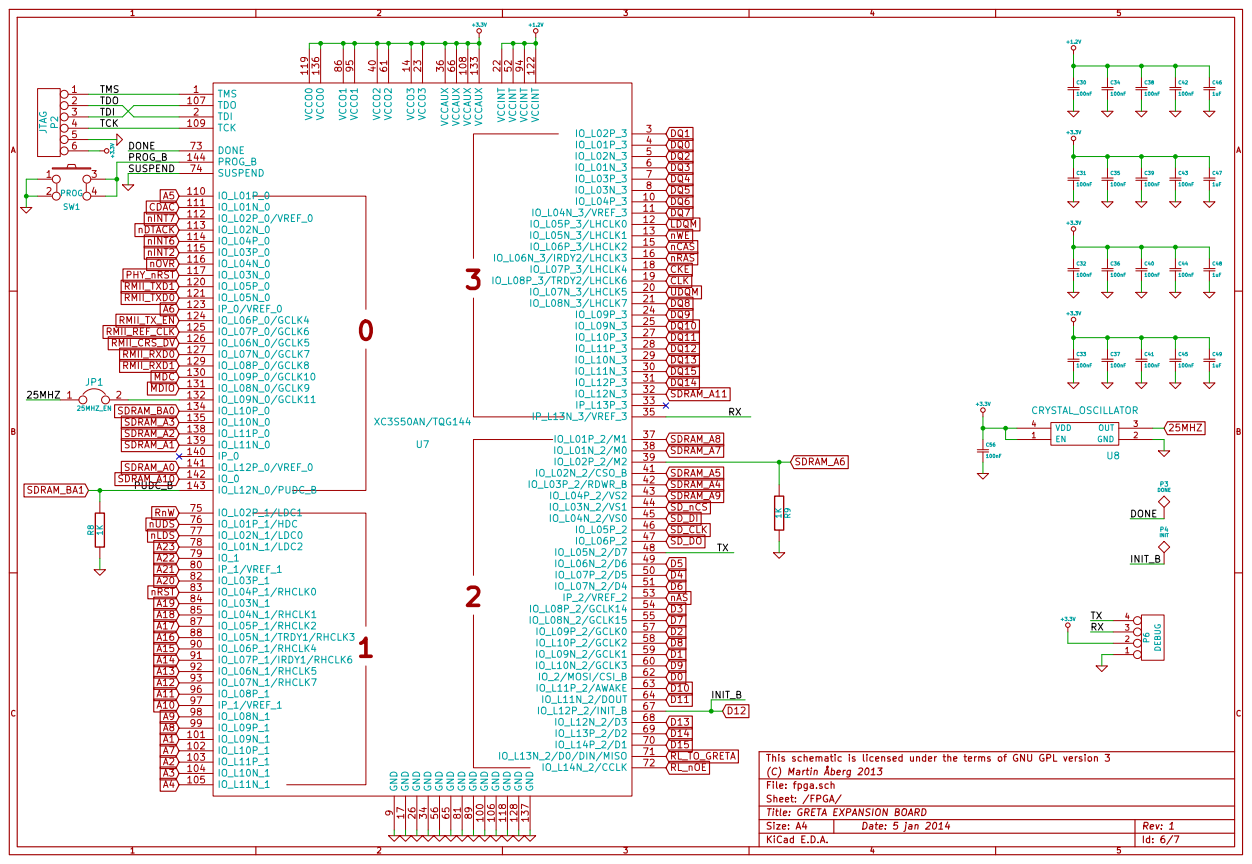
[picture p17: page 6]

This schematic is licensed under the terms of GNU GPL version 3
(C) Martin Åberg 2013
File: fpga.sch
Sheet: /FPGA/
Title: GRETA EXPANSION BOARD

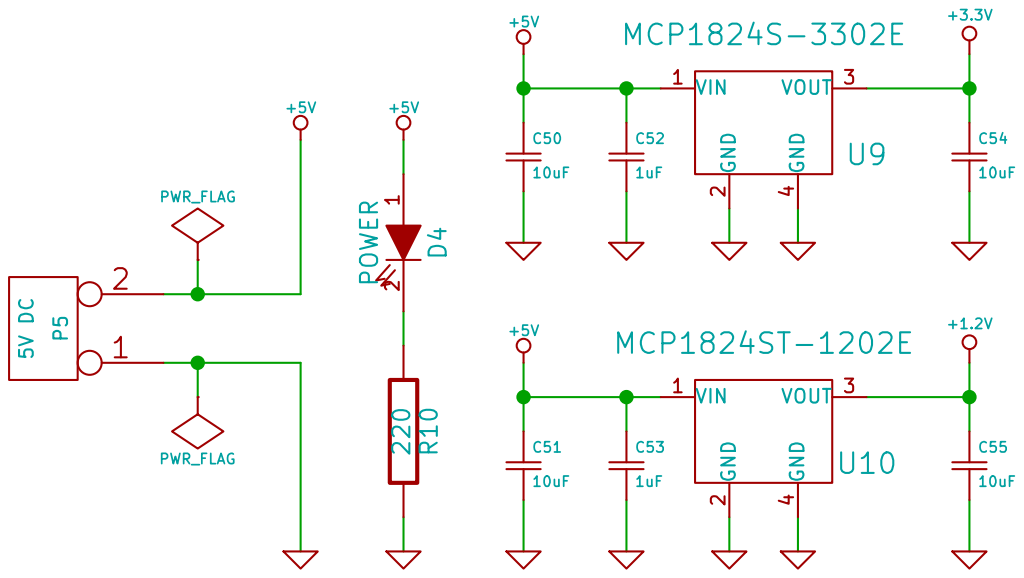
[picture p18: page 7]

This schematic is licensed under the terms of GNU GPL version 3
(C) Martin Åberg 2013
File: power.sch
Sheet: /Power supply/
Title: GRETA EXPANSION BOARD

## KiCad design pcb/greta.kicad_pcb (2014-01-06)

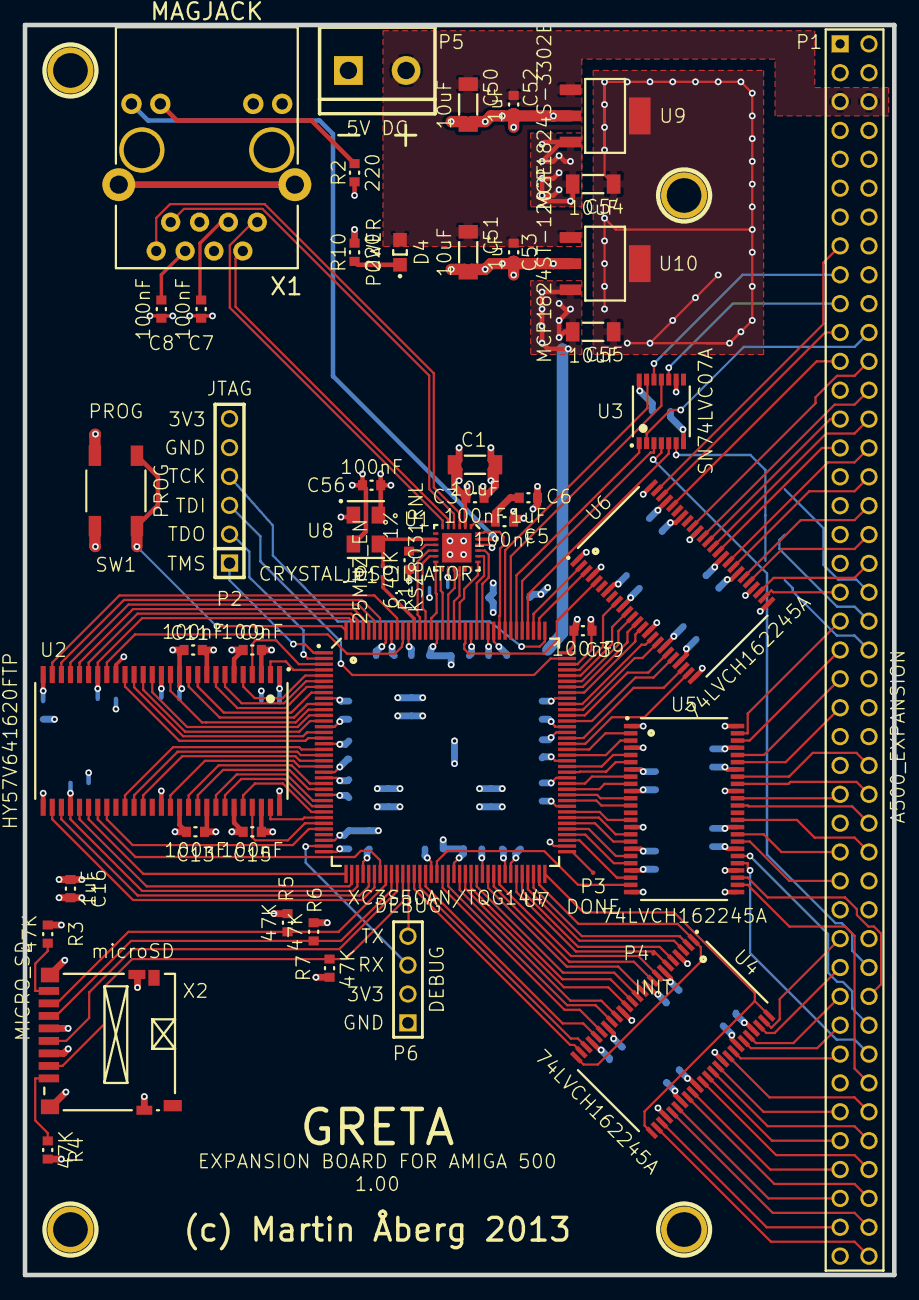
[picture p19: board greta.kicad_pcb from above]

Board: 4 copper layers, 76.5 x 110.0 mm, 94 parts (0 on the bottom side), 184 nets.

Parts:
C1, C2, C50, C51, C54, C55: 10uF; CAP3216
C3, C4, C5, C7, C8, C9, C10, C11, C12, C13, C14, C15, C17, C18, C19, C20, C21, C22, C23, C24, C25, C26, C27, C28, C29, C30, C31, C32, C33, C34, C35, C36, C37, C38, C39, C40, C41, C42, C43, C44, C45, C56: 100nF; CAP1608
C6, C16, C46, C47, C48, C49, C52, C53: 1uF; CAP1608
D1, D2, D3: B0520WS; SOD-323
D4: POWER; LED2012
JP1: 25MHZ_EN; JUMPER2
NE: P***; 1pin
NW: P***; 1pin
P1: A500_EXPANSION
P2: JTAG; PIN_ARRAY-6X1
P3: DONE; TESTPOINT
P4: INIT; TESTPOINT
P5: 5V DC; bornier2
P6: DEBUG; PIN_ARRAY_4x1
R1: 6.49K 1%; RES1608
R2, R10: 220; RES1608
R3, R4, R5, R6, R7: 47K; RES1608
R8, R9: 1K; RES1608
SE: P***; 1pin
SW: P***; 1pin
SW1: PROG; BUTTON52x52
U1: KSZ8031RNL; QFN44-24
U2: HY57V641620FTP; TSOP2-54
U3: SN74LVC07A; TSSOP14
U4, U5, U6: 74LVCH162245A; SSOP48
U7: XC3S50AN/TQG144; TQ144
U8: CRYSTAL_OSCILLATOR; OSC50x32
U9: MCP1824S-3302E; SOT-223
U10: MCP1824ST-1202E; SOT-223
X1: MAGJACK
X2: MICRO_SD

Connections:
25MHZ: JP1.1, U1.8, U8.3
+1.2V: C30.1, C34.1, C38.1, C42.1, C46.1, C55.1, U7.22, U7.52, U7.94, U7.122, U10.3
+3.3V: C1.1, C2.1, C3.1, C4.1, C9.1, C10.1, C11.1, C12.1, C13.1, C14.1, C15.1, C16.1, C17.1, C18.1, C19.1, C20.1, C21.1, C22.1, C23.1, C24.1, C25.1, C26.1, C27.1, C28.1, C29.1, C31.1, C32.1, C33.1, C35.1, C36.1, C37.1, C39.1, C40.1, C41.1, C43.1, C44.1, C45.1, C47.1, C48.1, C49.1, C54.1, C56.1, P2.6, P6.2, R2.1, R3.1, R4.1, R5.1, R6.1, R7.1, U1.2, U1.14, U2.1, U2.3, U2.9, U2.14, U2.27, U2.43, U2.49, U3.14, U4.7, U4.18, U4.31, U4.42, U5.1, U5.7, U5.18, U5.24, U5.31, U5.42, U6.1, U6.7, U6.18, U6.24, U6.31, U6.42, U7.14, U7.23, U7.36, U7.40, U7.61, U7.66, U7.86, U7.95, U7.108, U7.119, U7.133, U7.136, U8.1, U8.4, U9.3, X2.4
+5V: C50.1, C51.1, C52.1, C53.1, D4.1, P1.5, P1.6, P5.2, U9.1, U10.1
/FPGA/DONE: P3.1, U7.73
/FPGA/PROG_B: SW1.3, SW1.4, U7.144
/FPGA/RX: P6.3, U7.35
/FPGA/TCK: P2.4, U7.109
/FPGA/TDI: P2.3, U7.107
/FPGA/TDO: P2.2, U7.2
/FPGA/TMS: P2.1, U7.1
/FPGA/TX: P6.4, U7.48
/Rock Lobster/RL_A1: P1.29, U6.35
/Rock Lobster/RL_A2: P1.27, U6.37
/Rock Lobster/RL_A3: P1.26, U6.38
/Rock Lobster/RL_A4: P1.24, U6.40
/Rock Lobster/RL_A5: P1.21, U6.46
/Rock Lobster/RL_A6: P1.23, U6.44
/Rock Lobster/RL_A7: P1.28, U6.36
/Rock Lobster/RL_A8: P1.30, U6.33
/Rock Lobster/RL_A9: P1.32, U6.32
/Rock Lobster/RL_A10: P1.34, U6.30
/Rock Lobster/RL_A11: P1.36, U6.29
/Rock Lobster/RL_A12: P1.38, U6.27
/Rock Lobster/RL_A13: P1.39, U6.26
/Rock Lobster/RL_A14: P1.41, U5.47
/Rock Lobster/RL_A15: P1.43, U5.46
/Rock Lobster/RL_A16: P1.45, U5.44
/Rock Lobster/RL_A17: P1.47, U5.43
/Rock Lobster/RL_A18: P1.52, U5.41
/Rock Lobster/RL_A19: P1.54, U5.40
/Rock Lobster/RL_A20: P1.56, U5.37
/Rock Lobster/RL_A21: P1.58, U5.35
/Rock Lobster/RL_A22: P1.57, U5.33
/Rock Lobster/RL_A23: P1.59, U5.32
/Rock Lobster/RL_CDAC: P1.15, U6.47
/Rock Lobster/RL_D0: P1.75, U4.38
/Rock Lobster/RL_D1: P1.77, U4.36
/Rock Lobster/RL_D2: P1.79, U4.33
/Rock Lobster/RL_D3: P1.81, U4.30
/Rock Lobster/RL_D4: P1.83, U4.27
/Rock Lobster/RL_D5: P1.86, U4.26
/Rock Lobster/RL_D6: P1.84, U4.29
/Rock Lobster/RL_D7: P1.82, U4.32
/Rock Lobster/RL_D8: P1.80, U4.35
/Rock Lobster/RL_D9: P1.78, U4.37
/Rock Lobster/RL_D10: P1.76, U4.40
/Rock Lobster/RL_D11: P1.71, U4.41
/Rock Lobster/RL_D12: P1.69, U4.43
/Rock Lobster/RL_D13: P1.67, U4.44
/Rock Lobster/RL_D14: P1.65, U4.46
/Rock Lobster/RL_D15: P1.63, U4.47
/Rock Lobster/RL_RnW: P1.68, U5.27
/Rock Lobster/RL_nAS: P1.74, U5.26
/Rock Lobster/RL_nDTACK: P1.66, U3.4
/Rock Lobster/RL_nINT2: P1.19, U3.10
/Rock Lobster/RL_nINT6: P1.22, U3.2
/Rock Lobster/RL_nINT7: D1.2, D2.2, D3.2, U3.6
/Rock Lobster/RL_nLDS: P1.70, U5.30
/Rock Lobster/RL_nOVR: P1.17, U3.12
/Rock Lobster/RL_nRST: P1.53, U5.38
/Rock Lobster/RL_nUDS: P1.72, U5.29
A1: U6.14, U7.101
A2: U6.12, U7.103
A3: U6.11, U7.104
A4: U6.9, U7.105
A5: U6.3, U7.110
A6: U6.5, U7.123
A7: U6.13, U7.102
A8: U6.16, U7.99
A9: U6.17, U7.98
A10: U6.19, U7.97
A11: U6.20, U7.96
A12: U6.22, U7.93
A13: U6.23, U7.92
A14: U5.2, U7.91
A15: U5.3, U7.90
A16: U5.5, U7.88
A17: U5.6, U7.87
A18: U5.8, U7.85
A19: U5.9, U7.84
A20: U5.12, U7.82
A21: U5.14, U7.80
A22: U5.16, U7.79
A23: U5.17, U7.78
CDAC: U6.2, U7.111
CKE: U2.37, U7.18
CLK: U2.38, U7.19
D0: U4.11, U7.62
D1: U4.13, U7.59
D2: U4.16, U7.57
D3: U4.19, U7.54
D4: U4.22, U7.50
D5: U4.23, U7.49
D6: U4.20, U7.51
D7: U4.17, U7.55
D8: U4.14, U7.58
D9: U4.12, U7.60
D10: U4.9, U7.63
D11: U4.8, U7.64
D12: P4.1, U4.6, U7.67
D13: U4.5, U7.68
D14: U4.3, U7.69
D15: U4.2, U7.70
DQ0: U2.2, U7.4
DQ1: U2.4, U7.3
DQ2: U2.5, U7.5
DQ3: U2.7, U7.6
DQ4: U2.8, U7.7
DQ5: U2.10, U7.8
DQ6: U2.11, U7.10
DQ7: U2.13, U7.11
DQ8: U2.42, U7.21
DQ9: U2.44, U7.24
DQ10: U2.45, U7.25
DQ11: U2.47, U7.27
DQ12: U2.48, U7.28
DQ13: U2.50, U7.29
DQ14: U2.51, U7.31
DQ15: U2.53, U7.30
GND: C1.2, C2.2, C3.2, C4.2, C5.2, C6.2, C7.2, C8.2, C9.2, C10.2, C11.2, C12.2, C13.2, C14.2, C15.2, C16.2, C17.2, C18.2, C19.2, C20.2, C21.2, C22.2, C23.2, C24.2, C25.2, C26.2, C27.2, C28.2, C29.2, C30.2, C31.2, C32.2, C33.2, C34.2, C35.2, C36.2, C37.2, C38.2, C39.2, C40.2, C41.2, C42.2, C43.2, C44.2, C45.2, C46.2, C47.2, C48.2, C49.2, C50.2, C51.2, C52.2, C53.2, C54.2, C55.2, C56.2, P1.1, P1.2, P1.3, P1.4, P1.12, P1.13, P1.25, P1.37, P1.49, P1.61, P1.73, P1.85, P2.5, P5.1, P6.1, R1.2, R8.1, R9.2, R10.2, SW1.1, SW1.2, U1.22, U1.25, U2.6, U2.12, U2.19, U2.28, U2.41, U2.46, U2.52, U2.54, U3.7, U3.9, U4.4, U4.10, U4.15, U4.21, U4.28, U4.34, U4.39, U4.45, U5.4, U5.10, U5.15, U5.21, U5.25, U5.28, U5.34, U5.39, U5.45, U5.48, U6.4, U6.10, U6.15, U6.21, U6.25, U6.28, U6.34, U6.39, U6.45, U6.48, U7.9, U7.17, U7.26, U7.34, U7.56, U7.65, U7.74, U7.81, U7.89, U7.100, U7.106, U7.118, U7.128, U7.137, U8.2, U9.2, U9.4, U10.2, U10.4, X2.6, X2.9, X2.10, X2.12, X2.13
GNDPWR: X1.13, X1.14
LDQM: U2.15, U7.12
MDC: U1.11, U7.130
MDIO: U1.10, U7.131
unnamed: D4.2, R10.1
unnamed: JP1.2, U7.132
unnamed: D1.1, P1.40
unnamed: D2.1, P1.42
unnamed: D3.1, P1.44
unnamed: R3.2, X2.1
unnamed: R4.2, X2.8
unnamed: U1.3, X1.8
unnamed: U1.5, X1.2
unnamed: C7.1, X1.3
unnamed: U1.23, X1.12
unnamed: C8.1, X1.6
unnamed: R2.2, X1.11
unnamed: U1.6, X1.1
unnamed: U1.4, X1.7
unnamed: R1.1, U1.9
unnamed: C5.1, C6.1, U1.1
PHY_nRST: U1.24, U7.117
RL_TO_GRETA: U4.1, U4.24, U7.71
RL_nOE: U4.25, U4.48, U7.72
RMII_CRS_DV: U1.15, U7.126
RMII_REF_CLK: U1.16, U7.125
RMII_RXD0: U1.13, U7.127
RMII_RXD1: U1.12, U7.129
RMII_TXD0: U1.20, U7.121
RMII_TXD1: U1.21, U7.120
RMII_TX_EN: U1.19, U7.124
RnW: U5.22, U7.75
SDRAM_A0: U2.23, U7.141
SDRAM_A1: U2.24, U7.139
SDRAM_A2: U2.25, U7.138
SDRAM_A3: U2.26, U7.135
SDRAM_A4: U2.29, U7.42
SDRAM_A5: U2.30, U7.41
SDRAM_A6: R9.1, U2.31, U7.39
SDRAM_A7: U2.32, U7.38
SDRAM_A8: U2.33, U7.37
SDRAM_A9: U2.34, U7.43
SDRAM_A10: U2.22, U7.142
SDRAM_A11: U2.35, U7.32
SDRAM_BA0: U2.20, U7.134
SDRAM_BA1: R8.2, U2.21, U7.143
SD_CLK: U7.46, X2.5
SD_DI: R6.2, U7.45, X2.3
SD_DO: R7.2, U7.47, X2.7
SD_nCS: R5.2, U7.44, X2.2
UDQM: U2.39, U7.20
nAS: U5.23, U7.53
nCAS: U2.17, U7.15
nDTACK: U3.3, U7.113
nINT2: U3.11, U7.115
nINT6: U3.1, U7.114
nINT7: U3.5, U7.112
nLDS: U5.19, U7.77
nOVR: U3.13, U7.116
nRAS: U2.18, U7.16
nRST: U5.11, U7.83
nUDS: U5.20, U7.76
nWE: U2.16, U7.13

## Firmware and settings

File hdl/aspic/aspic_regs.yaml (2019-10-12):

name: ASPIC
brief: SPI controller for GRETA
regs:
  - name:   cap
    brief:  Capability register
    width:  16
    fields:
      - name:   dma
        brief:  DMA available (R)
        pos:    0

  - name:   status
    brief:  Status register
    width:  16
    fields:
      - name:   tip
        brief:  Transfer in progress (R)
        pos:    0
      - name:   tc
        brief:  Transfer complete (R, write '1' to clear)
        pos:    1

  - name:   ctrl
    brief:  Control register
    width:  16
    fields:
      - name:   ss
        brief:  Slave select (RW)
        pos:    0

      - name:   tcim
        brief:  Transfer complete interrupt mask (RW)
        pos:    1

  - name:   scaler
    brief:  SPI clock scaler register
    width:  16
    fields:
      - name:   reload
        brief:  Scaler reload value (RW)
        pos:    0
        width:  16

  - name:   txdata
    brief:  SPI transmit data register
    width:  16
    fields:
      - name:   txdata
        brief:  Transmit data (RW)
        pos:    0
        width:  16

  - name:   rxdata
    brief:  SPI receive data register
    width:  16
    fields:
      - name:   rxdata
        brief:  Receive data (R)
        pos:    0
        width:  16

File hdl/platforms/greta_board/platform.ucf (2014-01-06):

#
# Copyright (C) 2013 Martin Åberg
#
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
CONFIG VCCAUX=3.3;
VOLTAGE = 1.2;

#NET "*" IOB = TRUE;
#NET "*" IOSTANDARD = LVCMOS33;
#NET "*" DRIVE = 6;
#INST "*" IOB = FORCE;
CONFIG PROHIBIT = P140;
CONFIG PROHIBIT = P33;
NET "CLK25MHZ" IOSTANDARD = LVCMOS33;
NET "CLK25MHZ" LOC = P132;
NET "DEBUG_RX" IOSTANDARD = LVCMOS33;
NET "DEBUG_RX" LOC = P35;
NET "DEBUG_TX" IOSTANDARD = LVCMOS33;
NET "DEBUG_TX" LOC = P48;
NET "PHY_MDC" IOSTANDARD = LVCMOS33;
NET "PHY_MDC" LOC = P130;
NET "PHY_MDIO" IOSTANDARD = LVCMOS33;
NET "PHY_MDIO" LOC = P131;
NET "PHY_MDIO" PULLUP;
NET "PHY_nRST" IOSTANDARD = LVCMOS33;
NET "PHY_nRST" LOC = P117;
NET "RL_A[10]" IOSTANDARD = LVCMOS33;
NET "RL_A[10]" LOC = P97;
NET "RL_A[11]" IOSTANDARD = LVCMOS33;
NET "RL_A[11]" LOC = P96;
NET "RL_A[12]" IOSTANDARD = LVCMOS33;
NET "RL_A[12]" LOC = P93;
NET "RL_A[13]" IOSTANDARD = LVCMOS33;
NET "RL_A[13]" LOC = P92;
NET "RL_A[14]" IOSTANDARD = LVCMOS33;
NET "RL_A[14]" LOC = P91;
NET "RL_A[15]" IOSTANDARD = LVCMOS33;
NET "RL_A[15]" LOC = P90;
NET "RL_A[16]" IOSTANDARD = LVCMOS33;
NET "RL_A[16]" LOC = P88;
NET "RL_A[17]" IOSTANDARD = LVCMOS33;
NET "RL_A[17]" LOC = P87;
NET "RL_A[18]" IOSTANDARD = LVCMOS33;
NET "RL_A[18]" LOC = P85;
NET "RL_A[19]" IOSTANDARD = LVCMOS33;
NET "RL_A[19]" LOC = P84;
NET "RL_A[1]" IOSTANDARD = LVCMOS33;
NET "RL_A[1]" LOC = P101;
NET "RL_A[20]" IOSTANDARD = LVCMOS33;
NET "RL_A[20]" LOC = P82;
NET "RL_A[21]" IOSTANDARD = LVCMOS33;
NET "RL_A[21]" LOC = P80;
NET "RL_A[22]" IOSTANDARD = LVCMOS33;
NET "RL_A[22]" LOC = P79;
NET "RL_A[23]" IOSTANDARD = LVCMOS33;
NET "RL_A[23]" LOC = P78;
NET "RL_A[2]" IOSTANDARD = LVCMOS33;
NET "RL_A[2]" LOC = P103;
NET "RL_A[3]" IOSTANDARD = LVCMOS33;
NET "RL_A[3]" LOC = P104;
NET "RL_A[4]" IOSTANDARD = LVCMOS33;
NET "RL_A[4]" LOC = P105;
NET "RL_A[5]" IOSTANDARD = LVCMOS33;
NET "RL_A[5]" LOC = P110;
NET "RL_A[6]" IOSTANDARD = LVCMOS33;
NET "RL_A[6]" LOC = P123;
NET "RL_A[7]" IOSTANDARD = LVCMOS33;
NET "RL_A[7]" LOC = P102;
NET "RL_A[8]" IOSTANDARD = LVCMOS33;
NET "RL_A[8]" LOC = P99;
NET "RL_A[9]" IOSTANDARD = LVCMOS33;
NET "RL_A[9]" LOC = P98;
NET "RL_CDAC" IOSTANDARD = LVCMOS33;
NET "RL_CDAC" LOC = P111;
NET "RL_D[0]" IOSTANDARD = LVCMOS33;
NET "RL_D[0]" LOC = P62;
NET "RL_D[10]" IOSTANDARD = LVCMOS33;
NET "RL_D[10]" LOC = P63;
NET "RL_D[11]" IOSTANDARD = LVCMOS33;
NET "RL_D[11]" LOC = P64;
NET "RL_D[12]" IOSTANDARD = LVCMOS33;
NET "RL_D[12]" LOC = P67;
NET "RL_D[13]" IOSTANDARD = LVCMOS33;
NET "RL_D[13]" LOC = P68;
NET "RL_D[14]" IOSTANDARD = LVCMOS33;
NET "RL_D[14]" LOC = P69;
NET "RL_D[15]" IOSTANDARD = LVCMOS33;
NET "RL_D[15]" LOC = P70;
NET "RL_D[1]" IOSTANDARD = LVCMOS33;
NET "RL_D[1]" LOC = P59;
NET "RL_D[2]" IOSTANDARD = LVCMOS33;
NET "RL_D[2]" LOC = P57;
NET "RL_D[3]" IOSTANDARD = LVCMOS33;
NET "RL_D[3]" LOC = P54;
NET "RL_D[4]" IOSTANDARD = LVCMOS33;
NET "RL_D[4]" LOC = P50;
NET "RL_D[5]" IOSTANDARD = LVCMOS33;
NET "RL_D[5]" LOC = P49;
NET "RL_D[6]" IOSTANDARD = LVCMOS33;
NET "RL_D[6]" LOC = P51;
NET "RL_D[7]" IOSTANDARD = LVCMOS33;
NET "RL_D[7]" LOC = P55;
NET "RL_D[8]" IOSTANDARD = LVCMOS33;
NET "RL_D[8]" LOC = P58;
NET "RL_D[9]" IOSTANDARD = LVCMOS33;
NET "RL_D[9]" LOC = P60;
NET "RL_D_nOE" IOSTANDARD = LVCMOS33;
NET "RL_D_nOE" LOC = P72;
NET "RL_D_TO_GRETA" IOSTANDARD = LVCMOS33;
NET "RL_D_TO_GRETA" LOC = P71;
NET "RL_nAS" IOSTANDARD = LVCMOS33;
NET "RL_nAS" LOC = P53;
NET "RL_nDTACK" IOSTANDARD = LVCMOS33;
NET "RL_nDTACK" LOC = P113;
NET "RL_nINT2" IOSTANDARD = LVCMOS33;
NET "RL_nINT2" LOC = P115;
NET "RL_nINT6" IOSTANDARD = LVCMOS33;
NET "RL_nINT6" LOC = P114;
NET "RL_nINT7" IOSTANDARD = LVCMOS33;
NET "RL_nINT7" LOC = P112;
NET "RL_nLDS" IOSTANDARD = LVCMOS33;
NET "RL_nLDS" LOC = P77;
NET "RL_nOVR" IOSTANDARD = LVCMOS33;
NET "RL_nOVR" LOC = P116;
NET "RL_nRST" IOSTANDARD = LVCMOS33;
NET "RL_nRST" LOC = P83;
NET "RL_nUDS" IOSTANDARD = LVCMOS33;
NET "RL_nUDS" LOC = P76;
NET "RL_RnW" IOSTANDARD = LVCMOS33;
NET "RL_RnW" LOC = P75;
NET "RMII_CRS_DV" IOSTANDARD = LVCMOS33;
NET "RMII_CRS_DV" LOC = P126;
NET "RMII_REF_CLK" IOSTANDARD = LVCMOS33;
NET "RMII_REF_CLK" LOC = P125;
NET "RMII_RXD[0]" IOSTANDARD = LVCMOS33;
NET "RMII_RXD[0]" LOC = P127;
NET "RMII_RXD[1]" IOSTANDARD = LVCMOS33;
NET "RMII_RXD[1]" LOC = P129;
NET "RMII_TXD[0]" IOSTANDARD = LVCMOS33;
NET "RMII_TXD[0]" LOC = P121;
NET "RMII_TXD[1]" IOSTANDARD = LVCMOS33;
NET "RMII_TXD[1]" LOC = P120;
NET "RMII_TX_EN" IOSTANDARD = LVCMOS33;
NET "RMII_TX_EN" LOC = P124;
NET "SDRAM_A[0]" IOSTANDARD = LVCMOS33;
NET "SDRAM_A[0]" LOC = P141;
NET "SDRAM_A[10]" IOSTANDARD = LVCMOS33;
NET "SDRAM_A[10]" LOC = P142;
NET "SDRAM_A[11]" IOSTANDARD = LVCMOS33;
NET "SDRAM_A[11]" LOC = P32;
NET "SDRAM_A[1]" IOSTANDARD = LVCMOS33;
NET "SDRAM_A[1]" LOC = P139;
NET "SDRAM_A[2]" IOSTANDARD = LVCMOS33;
NET "SDRAM_A[2]" LOC = P138;
NET "SDRAM_A[3]" IOSTANDARD = LVCMOS33;
NET "SDRAM_A[3]" LOC = P135;
NET "SDRAM_A[4]" IOSTANDARD = LVCMOS33;
NET "SDRAM_A[4]" LOC = P42;
NET "SDRAM_A[5]" IOSTANDARD = LVCMOS33;
NET "SDRAM_A[5]" LOC = P41;
NET "SDRAM_A[6]" IOSTANDARD = LVCMOS33;
NET "SDRAM_A[6]" LOC = P39;
NET "SDRAM_A[7]" IOSTANDARD = LVCMOS33;
NET "SDRAM_A[7]" LOC = P38;
NET "SDRAM_A[8]" IOSTANDARD = LVCMOS33;
NET "SDRAM_A[8]" LOC = P37;
NET "SDRAM_A[9]" IOSTANDARD = LVCMOS33;
NET "SDRAM_A[9]" LOC = P43;
NET "SDRAM_BA[0]" IOSTANDARD = LVCMOS33;
NET "SDRAM_BA[0]" LOC = P134;
NET "SDRAM_BA[1]" IOSTANDARD = LVCMOS33;
NET "SDRAM_BA[1]" LOC = P143;
NET "SDRAM_CKE" IOSTANDARD = LVCMOS33;
NET "SDRAM_CKE" LOC = P18;
NET "SDRAM_CLK" IOSTANDARD = LVCMOS33;
NET "SDRAM_CLK" LOC = P19;
NET "SDRAM_DQ[0]" IOSTANDARD = LVCMOS33;
NET "SDRAM_DQ[0]" LOC = P5;
NET "SDRAM_DQ[10]" IOSTANDARD = LVCMOS33;
NET "SDRAM_DQ[10]" LOC = P25;
NET "SDRAM_DQ[11]" IOSTANDARD = LVCMOS33;
NET "SDRAM_DQ[11]" LOC = P27;
NET "SDRAM_DQ[12]" IOSTANDARD = LVCMOS33;
NET "SDRAM_DQ[12]" LOC = P28;
NET "SDRAM_DQ[13]" IOSTANDARD = LVCMOS33;
NET "SDRAM_DQ[13]" LOC = P29;
NET "SDRAM_DQ[14]" IOSTANDARD = LVCMOS33;
NET "SDRAM_DQ[14]" LOC = P31;
NET "SDRAM_DQ[15]" IOSTANDARD = LVCMOS33;
NET "SDRAM_DQ[15]" LOC = P30;
NET "SDRAM_DQ[1]" IOSTANDARD = LVCMOS33;
NET "SDRAM_DQ[1]" LOC = P4;
NET "SDRAM_DQ[2]" IOSTANDARD = LVCMOS33;
NET "SDRAM_DQ[2]" LOC = P3;
NET "SDRAM_DQ[3]" IOSTANDARD = LVCMOS33;
NET "SDRAM_DQ[3]" LOC = P6;
NET "SDRAM_DQ[4]" IOSTANDARD = LVCMOS33;
NET "SDRAM_DQ[4]" LOC = P7;
NET "SDRAM_DQ[5]" IOSTANDARD = LVCMOS33;
NET "SDRAM_DQ[5]" LOC = P8;
NET "SDRAM_DQ[6]" IOSTANDARD = LVCMOS33;
NET "SDRAM_DQ[6]" LOC = P10;
NET "SDRAM_DQ[7]" IOSTANDARD = LVCMOS33;
NET "SDRAM_DQ[7]" LOC = P11;
NET "SDRAM_DQ[8]" IOSTANDARD = LVCMOS33;
NET "SDRAM_DQ[8]" LOC = P21;
NET "SDRAM_DQ[9]" IOSTANDARD = LVCMOS33;
NET "SDRAM_DQ[9]" LOC = P24;
NET "SDRAM_LDQM" IOSTANDARD = LVCMOS33;
NET "SDRAM_LDQM" LOC = P12;
NET "SDRAM_nCAS" IOSTANDARD = LVCMOS33;
NET "SDRAM_nCAS" LOC = P15;
NET "SDRAM_nRAS" IOSTANDARD = LVCMOS33;
NET "SDRAM_nRAS" LOC = P16;
NET "SDRAM_nWE" IOSTANDARD = LVCMOS33;
NET "SDRAM_nWE" LOC = P13;
NET "SDRAM_UDQM" IOSTANDARD = LVCMOS33;
NET "SDRAM_UDQM" LOC = P20;
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

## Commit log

2014-01-06 First public release.
    [ethernet.sch, fpga.sch, greta.kicad_pcb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]
2016-07-31 Common GRETA bus in signal
    A common gbus_in signal record can be input to all slaves. config_in is
    represented as a vector of all slaves. Added interrupt output.
2016-07-31 GRETA SPI controller
    - The controller performs one transaction at a time.
    - Level interrupt (maskable) is generated when transfer completes.
    - Optional slave select output with configurable polarity.
    - SPI clock frequency is programmable.
    - Register description is provided in aspic_regs.{yaml,vhdl,h}
2016-07-31 HDL design with SPI controller
2019-10-12 ASPIC: No automatic slave select
    The device driver is responsible for asserting SPI select.

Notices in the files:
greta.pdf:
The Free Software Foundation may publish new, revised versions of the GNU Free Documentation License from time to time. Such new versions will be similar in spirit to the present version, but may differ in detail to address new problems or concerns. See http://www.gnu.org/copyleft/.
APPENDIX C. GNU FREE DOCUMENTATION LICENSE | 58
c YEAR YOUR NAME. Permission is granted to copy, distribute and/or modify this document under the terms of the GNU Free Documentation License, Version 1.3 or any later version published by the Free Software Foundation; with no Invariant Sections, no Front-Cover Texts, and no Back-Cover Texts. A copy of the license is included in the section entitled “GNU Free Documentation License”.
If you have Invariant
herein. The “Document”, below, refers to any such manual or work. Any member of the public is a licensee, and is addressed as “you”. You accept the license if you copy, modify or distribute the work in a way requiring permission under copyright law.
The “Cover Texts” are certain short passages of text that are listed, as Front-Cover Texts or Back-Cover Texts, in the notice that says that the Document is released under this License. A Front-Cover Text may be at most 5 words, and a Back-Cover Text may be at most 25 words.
